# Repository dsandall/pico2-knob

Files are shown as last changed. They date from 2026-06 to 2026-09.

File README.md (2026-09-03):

# pico2-knob

A small **wireless BLE control puck**: a knob (rotary encoder), an OLED screen, and three
buttons, on a round Ø80 mm 2-layer PCB, powered by a **nice!nano v2** (nRF52840) + LiPo.

> Name is legacy — it started as an RP2350/Pico 2 board, then moved to the nice!nano for
> wireless. This repo is the hardware (schematic + layout), a rough mechanical mockup, and
> `firmware/` — currently just bring-up firmware (Rust/Embassy, UF2) for the soldered board:
> LED heartbeat plus encoder/button events over USB serial. No screen, battery or BLE yet.

## Open it
`hardware/pico2-knob.kicad_pro` in **KiCad 10**. The schematic embeds its symbols and the
board embeds its footprints, so it opens standalone; `lib/marbastlib` (nice!nano sym/fp) and
the project lib-tables are included so libraries resolve cleanly too.

## Board summary
- **MCU:** nice!nano v2 — mounted on the **back**, on female sockets, USB-C facing the top
  rim (charge/flash; the device is otherwise sealed and battery-powered over BLE).
- **Encoder:** Alps EC11 w/ pushbutton, shaft at the puck center.
- **Buttons:** 3 × 6 mm tactile (SW_PUSH_6mm), in an arc below the knob.
- **Display:** ER-OLED1.12-2 (SH1107) on a 20-pin ribbon connector (J3, ER-CON20HT-1),
  driven as 4-wire SPI. Panel VPP comes from a 12 V boost (U2, MC34063) off +BATT,
  gated by Q1 from `12V_EN`.
- **Power:** LiPo on a JST-PH (J2) → nice!nano on-board charger (BAT+/GND). No power switch
  (nRF52 sleeps at µA; add an inline slide switch in VBAT if you want true-off).
- **Outline:** Ø80 mm round (bumped up from Ø74 for fab edge-clearance on the nano pads).
- 2-layer, GND pours both sides, 55 tracks, 0 vias. **DRC: 0 errors.**

## Net / GPIO map (nRF52 pads)
| Signal | nice!nano pad |
|---|---|
| Encoder A / B / SW | P0.09 / P0.10 / P1.11 (pads 24 / 23 / 22) |
| Buttons 1 / 2 / 3 | P0.31 / P0.02 / P1.15 (pads 17 / 19 / 20) |
| OLED DC / SCLK / SDI | P0.06 / P0.08 / P0.17 (pads 1 / 2 / 5) |
| OLED RES / CS | P0.22 / P0.24 (pads 7 / 8), 10 kΩ pull-ups (R2/R6) |
| 12V_EN (panel rail) | P1.06 (pad 12), active low — R8 pulls Q1's gate to +BATT |
| Power | 3V3 (pad 16), GND, BAT+ → +BATT |

## For the reviewer 👀
This layout was **script-generated** (see `scripts/`) and auto-routed (freerouting), then
hand-touched at the encoder. Please sanity-check freely — a few notes:
- **2 DRC items are intentionally downgraded to warnings:** `pth_inside_courtyard` between
  the back-side socketed nano and the front-side encoder courtyard. The nano sits ~8.5 mm
  below the board on sockets, so there's no real clash — but please confirm you agree.
- The encoder signal nets stack collinearly under the nano; they're hand-routed
  (`scripts/manual_route.py`) and S2's GND return is a manual trace into the south pour
  (`scripts/fix_s2.py`).
- **Not yet done:** mounting features (holes/standoffs) — coming after the enclosure.
- Pin assignment is flexible (nRF52 GPIOs are interchangeable) — happy to remap for cleaner
  routing if you see a better arrangement.

## Layout of this repo
- `hardware/` — KiCad 10 project (schematic, PCB, lib-tables)
- `lib/marbastlib/` — nice!nano symbol + footprint (trimmed to what's used)
- `scripts/` — generators: `gen_sch.py`, `gen_pcb.py`, routing helpers; `*.sh` render/ERC/DRC
- `cad/` — FreeCAD mechanical mockup (`mockup.py`) + component STEP models (`step/`)
- `build/pico2-knob.pdf` — quick-look: schematic + routed layout

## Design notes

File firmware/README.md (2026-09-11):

# pico2joy bring-up firmware

Bring-up firmware for the assembled puck: **no battery, no BLE**. It exists to
answer "did I solder it right?" — it blinks the nice!nano's LED, drives the
SH1107 ribbon OLED, and streams every encoder detent and button edge over USB
serial while mirroring the same state on the screen.

Rust + [Embassy] on the nice!nano v2 (nRF52840), flashed as a UF2 over the stock
bootloader — no debugger or SWD pads needed.

[Embassy]: https://embassy.dev

## Build and flash

```sh
cargo run --release              # build -> UF2 -> reboot the board -> flash it
MONITOR=1 cargo run --release    # ...and attach picocom when it comes back
```

`cargo run` goes through `flash.sh` (wired up as the cargo `runner`). It packages
the ELF as a UF2, asks the running firmware to reboot into UF2 mode — via its `b`
command, falling back to the 1200-baud touch — waits for the drive, copies, and
waits for the app's serial port to reappear. `udisksctl` is used to mount the
drive if your desktop doesn't automount it.

A board that has never been flashed can't reboot itself, so the first time
(or any time you see "board is in the bootloader's serial-only mode"):

1. Plug in USB-C.
2. **Double-tap** the reset button on the nice!nano. A drive named `NICENANO` (or
   `FTHR840BOOT`) appears — a single tap only gets you the bootloader's serial
   port, no drive.
3. `cargo run --release`, or drag `out/pico2joy-bringup.uf2` onto the drive.

The script waits 20 s for the drive, so you can start it and then double-tap;
`WAIT=40` if you want longer. Build without flashing:

```sh
./build.sh                       # -> out/pico2joy-bringup.uf2 (BLE, the default)
./build.sh --no-ble              # -> out/pico2joy-bringup-noble.uf2
./build.sh --offset-1000         # the alternate flash layout, see below
```

The first boot after flashing writes `UICR.NFCPINS` (to free P0.09/P0.10 from the
NFC block, where encoder A/B live) and resets itself once. If that reset lands in
the bootloader's double-tap window, the board comes up in the bootloader instead —
just tap reset once and it runs. This happens at most once per chip.

## Use

Open the app's serial port — a *second* `/dev/ttyACM*` distinct from the
bootloader's, `1209:0001 softek pico2joy bring-up`:

```sh
picocom -b 115200 /dev/ttyACM1     # baud is ignored, it's USB CDC
```

Opening the port prints a banner; then events stream as you use the puck.
Set the port raw first, as picocom and `pico2joy.py` do: Linux hands every
freshly enumerated ttyACM over cooked, with echo on, and a tty with echo on
sends everything the puck prints straight back into its command parser — the
banner alone spells `p`, `i`, `2` and then `b`, a reboot into the bootloader.
The firmware defends itself (`ECHO_PROBE` in `main.rs`): it writes nothing
until DTR is up and the opener has had 100 ms to go raw, and if its own
greeting comes back it ignores single keys until the port is reopened, `#`
lines excepted. So a bare `cat /dev/ttyACM0` gets a warning line rather than a
puck stuck on the `FLASHING` screen.

```
[   12.345] BTN1 down
[   12.501] BTN1 up
[   13.002] ENC cw  detents=1
[   13.410] ENC_SW down
```

Single-key commands:

| key | does |
|---|---|
| `?` | help |
| `p` | inputs, detents, 12V_EN, battery, link state |
| `m` | open/close the on-screen menu (handy without hands on the puck) |
| `d` | next view: cube / gantry / xcarve / now playing / quota / orientation pattern |
| `i` | re-init the display (reset + full init sequence) |
| `f` | flip the panel 180 degrees (COM/segment remap) |
| `+`/`-` | contrast, in steps of 0x10 from the vendor default 0x4F |
| `e` | toggle the 12 V panel rail — panel off first on the way down |
| `w` | toggle the radio (advertising, or starting the BLE link) |
| `v` | verbose: log every encoder quadrature transition, not just detents  |
| `r` | quota screen: ask the bridge to check the vendors now |
| `l` | LED: dark / dim heartbeat / on |
| `b` | reboot into the UF2 bootloader |
| `#…`  | the machine channel — a line for the gantry bridge, not a keystroke |

## The control model

The device is a 3-axis jog controller, so that is the primitive everything else
is a view of: three jog counters plus a selected axis (`AXIS_COUNTS`, `AXIS` in
`main.rs`). **BTN1/2/3 select the axis, the knob jogs the selected one.**

Button-to-axis mapping lives in one line, `BUTTON_AXIS`, currently `Z, X, Y` in
button order; a build that wants `X, Y, Z` changes only that. The console can
drive the same model without hands on the puck: `1`/`2`/`3` select, `,`/`.` jog.

The **cube view** (second in the `d` cycle) renders those counters as a rotating
wireframe cube, with the three counts along the bottom. Hidden-line removal on a
convex solid is just backface culling: an edge is drawn exactly when at least one
of the two faces meeting at it faces the camera, so silhouette edges appear once
and the three edges meeting at the far corner never appear at all. It uses f32
and `libm` rather than fixed point, because the Cortex-M4F has a single-precision
FPU.

The cube's buttons are **momentary**, unlike everywhere else: hold BTN1/2/3 and
the knob jogs that axis and spins the cube about it, and with nothing held the
knob zooms. The knob applies **torque, not position** — a detent adds angular
momentum (about 0.52 rad/s), light drag bleeds it off with a ~5 s half-life, so a
flick sets it coasting and a counter-flick stops it.

The **gantry** and **xcarve** views, right after it, are real machines rather
than a model of one — see below.

## On the puck itself

- **Hold the knob in and turn it to change app.** One gesture reaches all seven
  screens from any of them, in either direction — which is more than `d` can do,
  and it costs no button, because a press was the only thing the knob did.
  The press is decided on release: turn in between and it was a switch, let go
  without turning and it was the menu.
- **Press the knob** to open the menu, **turn** to move, **BTN1/2/3** to select,
  **press the knob again** to leave — it's the same gesture in and out. Rows: `ble`, `12V rail`, `led`, `screen`, `jog step`,
  `home all`, `battery`, `exit` — each showing its current value on the right.
- The title bar says **which screen you are on**, the radio state, and the cell.
  It used to say `pico2joy` and carry a `12V` flag; neither earned its pixels —
  you can see it's the puck, and the rail flag was permanently lit (Q1 is flipped
  on this revision, so the rail can't be gated — and a board whose VPP *is* down
  has a dark panel nobody is reading a flag on). The rail keeps its menu row and
  its line in `p`, which is where a diagnostic belongs.
- Five screens, and every one of them is *about* something. The live input view
  and the all-pixels-on screen used to bracket them; both were bring-up
  instruments rather than things to look at. The pips told you a switch was
  wired, which `p` still reports and every other screen now proves by working,
  and lighting every pixel loaded VPP hard enough to find a weak boost — on a
  board whose rail can't be gated anyway. The orientation pattern stays, because
  a panel mounted the wrong way round is still worth one keystroke.
- **BTN1/2/3 mean whatever the screen is about**: the axis on the gantry, the
  transport on now-playing, the subscription on the quota screen. The knob is
  the same - jog, volume, or which account the gauge is showing.

## Driving a real printer

`tools/pico2joy.py` is the one host-side program: it finds the puck on USB or
BLE and speaks the same line protocol either way.

It serves several apps over that one link. `relay` owns the link and follows
the puck's screen - jog the gantry, turn the knob to the now-playing view and
the same knob is volume - because the machine channel is multiplexed by message
type and the puck announces its view with `#view`. `gantry`, `spotify` and
`quota` are that same relay pinned to one app, for a host that only has the one
job (the printer has no browser; a workstation may have no printer).

```
tools/pico2joy.py scan            # what can see the puck right now
tools/pico2joy.py monitor         # console passthrough
tools/pico2joy.py relay           # every app, following the puck's view
tools/pico2joy.py gantry          # just the gantry (relay pinned to one app)
tools/pico2joy.py xcarve          # just the X-Carve, through CNCJS
tools/pico2joy.py quota           # just the Claude/Codex rate-limit windows
tools/pico2joy.py flash out/pico2joy-bringup.uf2   # reflash, no reset button
tools/pico2joy.py reset uf2|serial|ota             # into a bootloader mode
```

Standard library only for everything over USB — the printer's system Python has
no pyserial, and a bring-up tool that needs a venv is a tool that doesn't get
run. BLE needs `bleak`, declared inline, so `uv run tools/pico2joy.py …` fetches
it and nothing else has to be installed.

Nobody here is a server. The program is a *client* of everything: it opens the
puck's port (or connects to it as a BLE central) and makes HTTP requests to
Moonraker, which is the only real server in the picture. So it runs wherever the
puck is attached — the printer host, or a workstation — with no listening
socket and no discovery. The one hard rule is that a serial port and a BLE
connection each have exactly one owner, so one copy of it owns the puck at a
time.

Run it on the printer, where Moonraker is localhost and trusted:

```
scp tools/pico2joy.py sovol@spi-xi:~/pico2joy/     # plug the puck in there
ssh sovol@spi-xi 'python3 ~/pico2joy/pico2joy.py gantry'   # localhost Moonraker
```

Moonraker only trusts requests from its `trusted_clients`, which is why the
gantry bridge is happiest on the printer. To run it from a workstation instead, pass
`--api-key`, add that host to `trusted_clients`, or let the tool tunnel the port
so the request arrives from localhost:

```
ssh -N -L 17125:127.0.0.1:7125 sovol@spi-xi        # by hand, or:
tools/pico2joy.py gantry --tunnel sovol@spi-xi     # does the forwarding for you
```

The puck is a **view of the machine, never a second copy of it**. Positions and
limits come from the printer; a detent produces a jog *request*, and the number
on screen doesn't move until Klipper reports that the head did. A jog that gets
refused — unhomed axis, mid-print, outside the travel — simply doesn't happen,
instead of leaving the puck lying about where the nozzle is.

Both directions share the console port. `#` opens a line on the machine channel;
every other byte is still a single-key command. Values are integer micrometres,
so neither end rounds twice:

| direction | line | meaning |
|---|---|---|
| host → puck | `#s <x> <y> <z> <homed-bits> <state>` | toolhead state, ~8 Hz |
| host → puck | `#l <xmin> <xmax> <ymin> <ymax> <zmin> <zmax>` | travel limits |
| host → puck | `#?` | identify |
| puck → host | `#j <axis> <delta-um>` | jog request |
| puck → host | `#c home` / `#c home_z` / `#c stop` | named command |
| puck → host | `#v 1` | identify reply |

No `#s` for 1.2 s and the screen says `offline` rather than showing a stale pose.
Jogs are coalesced one frame at a time, so spinning the knob fast becomes one
move rather than a queue of them, and they go out as a saved-state relative move:

```
SAVE_GCODE_STATE NAME=pico2joy_jog
G91
G1 X0.100 F6000
RESTORE_GCODE_STATE NAME=pico2joy_jog
```

On the gantry screen **BTN1/2/3 are X/Y/Z** (not the cube's `BUTTON_AXIS` order),
the knob jogs the selected axis by the step size from the menu (0.01 / 0.1 / 1 /
10 mm), and `home all` in the menu sends `#c home`. Each axis shows its position,
its travel as a bar with the head's place in it, and dashes if it isn't homed.

## Driving the X-Carve

The X-Carve has its own screen, `xcarve`, right after `gantry` — and it is the
same screen: the travel volume with the head in it, BTN1/2/3 for X/Y/Z, the knob
to jog, `home all` to home. Underneath it is a second `gantry::Machine` on its
own message types, the printer's lines with an `x` after the `#` — `#xs`/`#xl`
down, `#xj`/`#xc` up — so the two machines never read each other's state and
one relay could serve both.

The bridge lives on `rpi-xcarve`, the Pi that runs CNCJS next to the machine,
with the puck on its USB:

```
scp tools/pico2joy.py rpi-xcarve.netbird.cloud:pico2joy/
ssh rpi-xcarve.netbird.cloud 'python3 ~/pico2joy/pico2joy.py --link usb xcarve'
```

`tools/pico2joy-xcarve.service` runs the same thing at boot.

**CNCJS stays in charge of the machine.** It owns the X-Controller's serial port,
and the bridge joins that connection the way a second browser tab does, so the
CNCJS page and the puck work side by side. It doesn't take the port from anyone:
close it in CNCJS and the bridge waits until somebody opens it again. It speaks
socket.io over plain HTTP long-polling rather than a websocket, which keeps it
standard library only — the Pi has no pip to reach — and it signs its own token
with the secret in CNCJS's `~/.cncrc`, which is why it runs as the user CNCJS
runs as.

What GRBL changes, next to Klipper:

- **Positions are work coordinates** — the numbers CNCJS shows, the ones you
  zero. The travel limits go down in the same frame (machine travel
  `-$130..0`, shifted by the work offset), so the head still lands in the right
  place in the frame, and re-zeroing moves the limits along with it.
- **"Homed" means "not in Alarm".** GRBL has no per-axis flag; with homing on
  (`$22=1`) it boots into Alarm and stays there until `$H`. The catch is `$X`,
  which unlocks without homing and leaves the limits describing nothing — and
  soft limits are off on this machine (`$20=0`), so nothing below the puck would
  stop an over-travel either. Home it.
- **Jogs are `$J=` moves** — `$J=G91 G21 X0.100 F3000`, Z at 400 mm/min — which
  GRBL 1.1 keeps out of the modal state, so there is nothing to save and restore
  around them. They only go out from Idle, and never while a CNCJS job is running
  or paused: a paused job expects to find the head where it left it.
- `home all` is `$H`. `#xc stop` is a feed hold rather than a reset, so GRBL
  doesn't forget where the head is.
- **The finest jog step is one the machine can always take.** This X-Carve
  moves 0.0375 mm a step in X and Y (`$100`/`$101` = 26.66 steps/mm), so a
  0.01 mm detent mostly moved nothing at all. The bridge works out the coarsest
  axis's step from `$100`–`$102`, rounds it up to the 0.01 mm the screen shows,
  and sends it as `#xr 40`; the puck raises its finest step to 0.04 mm. GRBL
  rounds a move's end to whole steps, so a move at least one step long always
  turns into at least one.

### Zeroing the workpiece

On the `xcarve` screen the menu's first row is **`zero X`**, for whichever axis
BTN1/2/3 last picked; the rest of the menu scrolls below it. It makes the head's
position the work zero on that axis — `G10 L20 P1 X0` on the active coordinate
system, what CNCJS's zero buttons send. It takes a second press within three
seconds (the row says `again?`), because a stray zero throws away a workpiece
you already touched off. Once it zeroes, the menu closes and the axis reads 0.00.

So, per axis: jog to the spot, press that axis's button, click the knob, and
press a button twice on `zero`.

## Now playing (Spotify, or anything)

`tools/pico2joy.py spotify` turns the puck into a transport for whatever the
host is playing, and relays the album art back to the screen.

```
tools/pico2joy.py spotify              # over USB or BLE, whichever the puck is on
uv run tools/pico2joy.py spotify       # album art needs pillow, fetched by uv
```

It reads the **active MPRIS player** through `playerctl` (following `playerctld`,
so it tracks whatever you last touched) rather than Spotify's Web API - no OAuth,
no app registration, nothing to break when the API changes, and it works against
the Spotify *web player* in your browser exactly as it works against a desktop
app or, for that matter, a YouTube tab. Volume is the host's own output level via
`wpctl` (or `pactl`), because "louder" means the machine the music comes out of.

On the **now-playing screen** (fourth in the `d` cycle) the cover fills the frame
with a dark footer carrying title, artist and a volume bar. **BTN1/2/3 are
previous / play-pause / next**, and the **knob is volume**, five percent a detent.
With no bridge running the screen says so instead of showing a stale track.

The wire format is the same machine channel the gantry uses (`src/media.rs`):
`#ns`/`#nt`/`#na` carry play state, title and artist; the 128x128 one-bit cover
goes out as `#ab`, a run of `#a <seq> <hex>` rows, then `#ae`; and the puck sends
`#m p`/`#m n`/`#m b`/`#m v <steps>` back. One owner per link still holds, so the
puck drives the gantry or the player, not both at once.

## Subscription quotas

`tools/pico2joy.py quota` puts the state of your Claude and Codex plans on the
puck: how much of each short window is spent, how much of the week, how long
until the short one starts again, and how many sessions are running.

```
tools/pico2joy.py quota                       # ~/.claude and ~/.codex
tools/pico2joy.py quota --claude ~/.claude=me \
                        --claude work-box:~/.claude=work \
                        --codex ~/.codex
```

It reads the credentials each vendor's own CLI already keeps on disk and asks
the same usage endpoints those CLIs ask — `/api/oauth/usage` for Claude, the
ChatGPT backend's `wham/usage` for Codex. Nothing is counted here and nothing is
reconstructed from transcripts: a local token tally would be a second, wronger
copy of a number the vendor is authoritative for, which is the same reason the
gantry screen waits for Klipper rather than integrating its own jogs.

**Read-only, deliberately.** The access tokens in those directories are the
CLIs' to refresh; using the refresh token here could rotate it out from under a
running session and log you out of your own editor to draw a bar on a knob. So
an expired token shows `log in again` and waits for its CLI to renew it, which
happens the next time you use it.

The usage endpoints rate-limit, and a 429 is easy to earn and slow to clear — so
the default is a poll every five minutes, a 429 holds the last good reading
rather than blanking the screen, and the interval doubles on each failure until
it succeeds. Anthropic's `Retry-After` is honoured where it says anything useful
(it currently sends `0`). Five minutes of staleness costs nothing when holding a
button re-checks on demand, and `--refresh` moves it.

### More than one plan, and plans on other machines

The default is whatever is logged in on this machine, which for one Claude
subscription and one Codex is the whole configuration. **A second Claude account
needs a second config directory**, because Claude Code keeps one login per
directory and `/login` replaces it:

```sh
CLAUDE_CONFIG_DIR=~/.claude-work claude       # log the other account in, once
tools/pico2joy.py quota --claude ~/.claude=me --claude ~/.claude-work=work
```

If the other account lives on **another machine**, give it as `HOST:DIR` — scp's
spelling, and unambiguous because a local config directory has no colon:

```sh
tools/pico2joy.py quota --claude ~/.claude=me \
                        --claude design-desktop:~/.claude=work
```

That ships *this file* to the far end over ssh (`ssh host python3 - probe claude
~/.claude`), which reads the credentials, makes its own request, and prints one
JSON line back. Nothing is installed there and nothing is left behind — the same
bargain the rest of this tool makes. The token never crosses the network either:
`cat`ing the credentials home and calling the API from here would work, but there
is no reason to move a live OAuth token when the machine holding it can send back
six numbers instead. `tools/pico2joy.py probe claude ~/.claude` runs the same
reading locally, which is a good way to see exactly what the bridge sees.

`--claude`/`--codex` take `[HOST:]DIR` or `[HOST:]DIR=LABEL`; the label is what
shows on the row, and thirteen characters of it fit. Without one it takes the
account's display name or the local part of its email. Three accounts is the
limit — three buttons, three rows.

### On the screen

One block per account, all of them drawn all of the time. A name line carrying
the vendor, the sessions badge and the countdown to the short window's reset,
then a fat bar for that window and a thinner one for the week:

```
quota                     ble  88%
claude Dylan          [9]  1h47m
 5h ██████████████░░░░░░░░░  64%
 7d ███████░░░░░░░░░░░░░░░░  29%
codex engineering          1h12m
 5h ███████████████████████ 100%
 7d ██░░░░░░░░░░░░░░░░░░░░░   5%
```

Each bar carries its own label and number, drawn twice and clipped either side
of the fill boundary — lit over the empty part, dark over the filled part — so
the text stays legible at every value instead of vanishing into the bar around
half way. That is what buys the room for six bars on a 128-pixel screen without
a caption line above each one.

There is **nothing to select and nothing to page through**, which is the point:
the question this screen answers is "where do I stand", and an answer you have to
press a button to finish reading is a worse answer. **Holding a button** asks the
bridge to look again — the answer to "has it reset yet?" — and that is the only
control here. From the console that is `r`.

**Window names come from the bridge**, not from a constant in the firmware: `5h`
today, `6h` if a vendor moves, and **`7d/Fable`** when the weekly cap that
actually binds is one scoped to a model. Claude reports both an all-models weekly
figure and per-model ones, and the scoped one runs out first — a week that is 29%
gone overall can be 41% gone on the model you are using. The bar shows whichever
is higher and its label says which, because the useful number is the one you will
hit, not the flattering one.

**The badge is running sessions.** Neither vendor reports this, so it is counted
where the answer exists: the machine that account is logged in on, over the same
ssh hop as the reading. Top-level processes only — a session spawns helpers with
the same name, so counting every `claude` in `ps` says nine when three windows
are open — attributed by each process's `CLAUDE_CONFIG_DIR` (or `CODEX_HOME`), so
two accounts on one machine are counted apart. It is drawn only when there are
any, so an idle plan's line stays clean and a busy one announces itself.

The countdown is the one number computed on the puck. The bridge sends the
seconds left at the moment it asked and the puck turns that into a deadline on
its own clock, so the minutes tick between polls instead of freezing; every poll
re-syncs it. The host stays the authority and the puck only interpolates — the
same bargain the gantry makes with the toolhead position.

The wire format is the same machine channel (`src/quota.rs`): `#qz <count>` is
the heartbeat, `#qa` names a slot and its two windows, `#qu` carries the two
windows as percent and seconds-to-reset plus the session count and state, and the
puck sends `#q r` back. The vendors are polled on a worker thread, because a
usage request is a round trip to the internet and the loop that does it is also
the loop that reads the knob.

## Staying connected over BLE

The relay is happiest on the cable, but it does not need one. `--link ble` puts
it on the radio and keeps it there:

```
uv run tools/pico2joy.py --link ble relay --claude ~/.claude=me --codex ~/.codex
```

**This is the default build**, so `./build.sh`, `cargo run` and
`tools/pico2joy.py flash` all put it on the puck. `./build.sh --no-ble` gives the
broadcast-only firmware instead: a quarter of the flash, no radio stack to go
wrong, and no way to accept a connection — a useful thing to fall back to when
you are bisecting something, and useless for anything in this section.

**The link puts itself back together.** `BleLink`'s thread is not there to
connect once; it scans, connects, serves until the link drops, and starts again,
for as long as the program runs. Nothing above it knows. A forced disconnect
costs about four seconds:

```
14:37:32 ble: link down
14:37:36 ble: connected to C5:96:2F:91:CE:B8
14:37:37 relay: link back, resending
```

That last line is the part that matters. A puck that reconnected is a puck that
was told the toolhead position, the album art and three subscriptions before the
gap and remembers none of it, so the link counts its connections and the relay
resends everything on every new one — not just the first. Lines queued while the
link is down are **dropped**, not buffered: a jog delivered thirty seconds late
is worse than a jog that never happened.

`--link auto` still prefers the cable, and falls back to the radio when the cable
goes away — so unplugging USB mid-session moves the relay onto BLE rather than
ending it.

### Making Linux hold the link

Two things on the host are worth checking, because neither is our code:

**USB autosuspend on the Bluetooth controller.** This is the big one. `btusb`
ships with `enable_autosuspend=Y`, and on the MediaTek combo cards (`0e8d:*`, the
MT7921/7922 family) a suspended controller drops LE links and is slow to come
back. Check what yours has done:

```sh
cat /sys/class/bluetooth/hci0/device/../power/control          # "auto" is the problem
cat /sys/class/bluetooth/hci0/device/../power/runtime_suspended_time   # in ms
```

Pin it on, for this boot and for every boot:

```sh
echo on | sudo tee /sys/class/bluetooth/hci0/device/../power/control

# /etc/udev/rules.d/81-bt-no-autosuspend.rules — use your own vendor:product
ACTION=="add", SUBSYSTEM=="usb", ATTR{idVendor}=="0e8d", ATTR{power/control}="on"
```

**BlueZ's supervision timeout.** The central picks the connection parameters and
the puck has no say in them (see `src/ble.rs` for why — the GAP preferred-
parameters characteristic is a TODO in trouble-host 0.8). BlueZ's default tears
the link down over one missed window, which is easy to earn from a device you
pick up and carry. Four seconds of tolerance in `/etc/bluetooth/main.conf`:

```ini
[LE]
MinConnectionInterval=24
MaxConnectionInterval=48
ConnectionLatency=0
ConnectionSupervisionTimeout=400
```

(Units are 1.25 ms for the intervals and 10 ms for the timeout, so that is
30–60 ms and 4 s.) Then `systemctl restart bluetooth`. This is an optimisation
rather than a fix — the link recovers either way — but it turns a four-second
gap into no gap.

One more, if a connection succeeds and then behaves as though the puck has no
services: BlueZ caches a GATT database per address, and the puck's bootloader
advertises from an address one digit from the application's. The bridge notices
an empty service list and drops the cached record itself before retrying, so
this should heal on its own; `bluetoothctl remove <address>` is the manual
version, and `bluez-utils` is worth having installed for exactly that kind of
poking.

## Battery

The nice!nano v2 senses the cell through **VDDH**, not a divider pin, so this
samples VDDH/5 on the SAADC against the internal 0.6 V reference at gain 1/6:

    millivolts = raw * 18000 / 4096

Percent comes from a piecewise LiPo curve (`state::percent_from_mv`), because a
straight voltage-to-percent line is useless on a cell that sits at 3.8 V for
most of its life.

Two things to expect. On USB with no cell it reads about **4.54 V** — VBUS less
the input diode drop — and therefore claims 100%. And while charging it reads
the charger's output rather than the cell, so it will read full before the cell
is. Neither is worth correcting until a battery is actually on J2.

## What this actually tests

- nice!nano seated in its sockets, USB and the on-module LED alive.
- All three buttons, the encoder push, and both encoder phases. A cold joint on
  one encoder phase shows up as `step=0` noise under `v` instead of clean detents.
- The switch pull-ups at boot: `p` flags anything already reading low (a held
  button, or a short to GND on that net).
- **The SH1107 panel** on the J3 ribbon: the boot splash is an orientation test
  pattern (border, both diagonals, a solid block and `TL` in the top-left), then
  it switches to the cube, which is a live view of the encoder and the buttons
  in its own right: hold a button and turn, and the cube spins.
- **U2, the 12 V boost**, which the panel needs as external VPP (11.5–12.5 V, the
  panel's own DC-DC stays off via `0xAD 0x8A`). Brought up after the controller
  is initialised and dropped before it, and `e` toggles it.

Untested: the LiPo path (J2, `VBAT`).

### If the screen looks wrong

- **Mirrored or upside down** — press `f`. That flips COM scan and segment remap
  (`0xC8 0xA1` vs `0xC0 0xA0`), which is the assembly-orientation case.
- **Rotated 90 degrees** — already handled. This panel's RAM sits 90 degrees to
  the glass (an SH1107 page runs along the horizontal), and the controller only
  offers 180, so `Display::set_pixel` rotates on the way into the framebuffer:
  logical `(x, y)` lands at panel column `y`, row `127 - x`. If a future panel
  wants the plain mapping, that one line is the only thing to change — and note
  a bare transpose (column `y`, row `x`) rotates *and* mirrors.
- **Nothing at all, or faint** — check TP4 for ~12 V (`e`), then try `+` a few
  times. VPP below ~11.5 V reads as a dim or blank panel rather than an error.
- **Garbled but alive** — drop `spim::Frequency::M4` in `main.rs` to `M2`.

## Pinout

| Signal | nRF52840 | pad | Notes |
|---|---|-----|---|
| LED | P0.15 |  -  | on-module blue LED, active high |
| VCC_EN | P0.13 |  -  | nice!nano load switch: high = 3V3 pad live  |
| ENC_A | P0.09 | 24  | NFC pin, freed via `nfc-pins-as-gpio` |
| ENC_B | P0.10 | 23  | likewise |
| ENC_SW | P1.11 | 22  | |
| BTN1 | P0.31 | 17  | |
| BTN2 | P0.02 | 19  | |
| BTN3 | P1.15 | 20  | |
| OLED_DC | P0.06 |  1  | SH1107, 4-wire SPI over the J3 ribbon |
| OLED_SCLK | P0.08 |  2  | |
| OLED_SDI  | P0.17 |  5  | |
| OLED_RES  | P0.22 |  7  | 10k pull-up R2: boots out of reset |
| OLED_CS | P0.24 |  8  | 10k pull-up R6: boots deselected |
| 12V_EN | P1.06 | 12  | Q1 gate, **active low** — see below |

Taken from `board_pico2knob/pico2-knob.kicad_sch` (the checked-in
`bom_netlist.xml` is older than the ribbon-OLED rework — don't use it).

### 12V_EN is active low, and on this revision "off" isn't off

R8 pulls Q1's gate up to +BATT, so the rail is off with the gate high and on with
it pulled down. 3V3 is *not* a clean off — it leaves Vgs near -0.9 V, inside the
DMG3415U's threshold band — so the firmware drives the pin **low to enable** and
leaves it **disconnected (high-Z) to disable**, never high.

That said, Q1 looks flipped, so the rail can't actually be gated on this build:

- the schematic has Q1's **drain** on +BATT and its **source** on U2's Vin;
- the PCB footprint renames the SOT-23 pads `G`/`S`/`D` onto pads 1/2/3, which is
  exactly the DMG3415U's real pinout — so the physical drain is the +BATT one.

A P-channel high-side switch needs its *source* on the supply. Wired this way the
body diode (drain → source) conducts +BATT into U2's Vin whenever a cell or USB is
present, so U2 free-runs and the 12 V rail is always live, burning its quiescent
current on battery. `e` then only removes the diode drop rather than switching
anything.

To confirm on the bench: meter TP4 right after boot, before touching `e`. ~12 V
means the diode path is feeding U2. The rev-2 fix is swapping Q1's source and
drain (or dropping the FET and using U2's own shutdown).

## Flash layout / the two UF2s

The stock bootloader starts the app at **0x26000**, above the (unused) SoftDevice
slot, and asks the MBR to forward interrupts there — the same slot ZMK uses. That
is `out/pico2joy-bringup.uf2`, and it's the one to use. It carries the BLE stack;
`out/pico2joy-bringup-noble.uf2` (`./build.sh --no-ble`) is the same firmware
without it, and links at the same address.

If the bootloader on your board was built without a SoftDevice it will expect the
app at 0x1000 instead, and copying the default UF2 will appear to do nothing (the
drive just remounts). `out/pico2joy-bringup-0x1000.uf2` (`./build.sh
--offset-1000`) is linked for that case. `INFO_UF2.TXT` on the bootloader drive
names the bootloader build if you want to check first.

Neither variant touches the bootloader itself (0xF4000+), so double-tap reset
always gets you back.

## Next

- Battery: read VDDH via SAADC for a rough LiPo percentage (the nice!nano v2
  senses the cell through VDDH, not a divider pin).
- Sleep: the panel and the 12 V rail dominate the power budget, so idle wants
  display-off plus VPP down — which needs the Q1 fix above to actually work.
- BLE HID over `nrf-softdevice` or `trouble`, which is where the app at 0x26000
  starts mattering: a SoftDevice build has to move up to 0x27000.

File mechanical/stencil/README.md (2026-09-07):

# 3D-printed solder paste stencils

Generated with KiKit from `board_pico2knob/pico2-knob.kicad_pcb`.

## Which file to print

| Process | Top side | Bottom side |
|---|---|---|
| **FDM, 0.4 mm nozzle** | `topStencil-fdm.stl` | `bottomStencil-fdm-noJ3.stl` |
| **Resin (MSLA)** | `topStencil.stl` | `bottomStencil-noJ3.stl` |

The `-fdm` files have apertures enlarged 0.05 mm per side to offset FDM hole
shrinkage. Print them on FDM only — on resin they would over-dispense.

J3 is omitted from every bottom stencil meant for printing. `bottomStencil.stl`
retains it for reference only; see [J3](#j3).

## Regenerate

```sh
# resin
kikit stencil createprinted --pcbthickness 1.6 --thickness 0.2 \
  --framewidth 1.5 --frameclearance 0.1 \
  board_pico2knob/pico2-knob.kicad_pcb mechanical/stencil

# FDM (both sides, J3 omitted)
kikit stencil createprinted --pcbthickness 1.6 --thickness 0.2 \
  --framewidth 1.5 --frameclearance 0.1 --enlargeholes 0.05 --ignore J3 \
  board_pico2knob/pico2-knob.kicad_pcb mechanical/stencil/_fdm
```

KiKit always writes `topStencil.*` and `bottomStencil.*` into the output dir, so
the second run needs its files renamed to the `-fdm` names above and their
`.scad` DXF paths repointed at the top-level `.dxf` files. `--enlargeholes` is
applied in OpenSCAD, not in the DXF export, so both runs emit identical DXFs and
only one copy is kept.

Add `--ignore J3` to the first command for `bottomStencil-noJ3.*`.

## Parameters

| Option | Value | Why |
|---|---|---|
| `--pcbthickness` | 1.6 mm | board stackup thickness |
| `--thickness` | 0.2 mm | aperture depth = paste volume. 0.15 is closer to a steel stencil but is fragile printed; 0.3 would over-dispense onto U2's 0.6 mm pads and bridge |
| `--framewidth` | 1.5 mm | registration lip around the outline |
| `--frameclearance` | 0.1 mm | slip fit over the PCB edge; 0 is a press fit that print tolerance won't hit |
| `--enlargeholes` | 0.05 mm | FDM only — recovers hole shrinkage |

## Geometry

All variants 54.15 × 102.72 × 1.5 mm, watertight (0 non-manifold edges).
Height is 0.2 mm of stencil plate plus a 1.3 mm register lip that grips the
board edge.

Measured from the exported meshes, sliced mid-plate at z = 0.1 mm:

| File | Apertures | Min width | Min web | Web @ 0.33 mm extrusion |
|---|---|---|---|---|
| `topStencil.stl` | 19 | 0.600 mm | 0.655 mm | 2.0× |
| `topStencil-fdm.stl` | 19 | 0.700 mm | 0.553 mm | 1.7× |
| `bottomStencil-noJ3.stl` | 8 | 1.149 mm | 1.266 mm | 3.8× |
| `bottomStencil-fdm-noJ3.stl` | 8 | 1.249 mm | 1.166 mm | 3.5× |

The *web* is the wall left standing between adjacent apertures. On FDM it must
hold at least one extrusion, which is what constrains this board — not the
aperture width.

Per-part, from the board:

| Part | Side | Min aperture | Min web | Area ratio @0.2 mm |
|---|---|---|---|---|
| L1 | B | 2.90 mm | 7.00 mm | 4.72 |
| D1 | B | 1.80 mm | 1.50 mm | 2.62 |
| C1–C6 | F/B | 1.15 mm | 1.80 mm | 1.75 |
| U2 SOIC-8 | F | 0.60 mm | 0.67 mm | 1.15 |
| Q1 SOT-23 | F | 0.60 mm | 0.66 mm | 1.07 |
| J3 FPC | B | 0.30 mm | **0.20 mm** | **0.61** |

Area ratio > 0.66 is the paste-release rule, independent of process.

## Slicer settings — FDM

- **Extrusion width 0.33 mm.** This is the one setting that matters. The tightest
  web is 0.553 mm (Q1, U2); at the default 0.42 mm width that is 1.3 extrusions
  and the slicer may merge the two perimeters into a blob or drop the wall
  entirely. At 0.33 mm it is 1.7×, enough for a clean wall.
- **Layer height 0.1 mm**, so the 0.2 mm plate is 2 layers rather than 1. A
  single-layer sheet this size is floppy and delaminates from the frame.
- No supports inside the apertures; print plate-side down, flat on the bed.
- Turn off elephant-foot compensation — it eats the aperture edges, which the
  0.05 mm enlargement has already accounted for.

`bottomStencil-fdm-noJ3.stl` is undemanding (1.166 mm webs) and prints on
defaults. Only the top stencil needs the width change.

## J3

`bottomStencil.stl` includes J3 (ER-CON20HT-1, 0.3 mm apertures on 0.5 mm
pitch). Its 0.20 mm web is under half an extrusion, and its 0.61 area ratio
fails the release rule even for laser-cut steel at this thickness. It is kept
only as a reference for ordering a thinner steel stencil later. Drag-solder or
hot-air J3 by hand.

## Use

1. Paste and reflow the bottom side first, while the top is still bare and sits
   flat.
2. Then the top side. L1 (12×12×6 mm) and U1 on the bottom stand proud, so
   support the board on a jig or foam — the stencil registers only on the
   perimeter and will rock otherwise.
3. Hand-solder J3.
4. THT parts (R1–R8, SW1–SW3, RE1, J2) go in after both reflows.

## Files

`*.scad` is the OpenSCAD source; `*.dxf` are the paste and Edge.Cuts exports it
imports. The `.scad` files reference the `.dxf` files by **absolute path**, so
moving this directory breaks re-rendering — but not the already-exported STLs.
Regenerate rather than relocate.

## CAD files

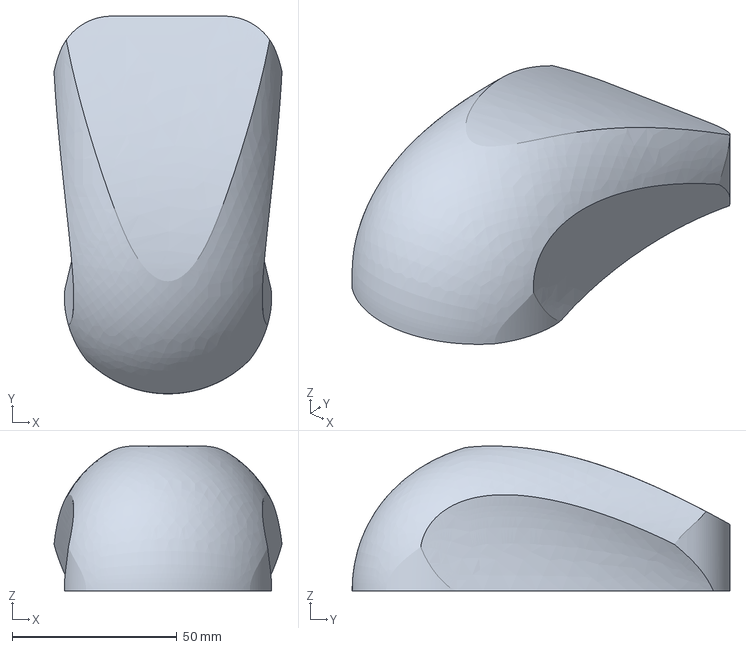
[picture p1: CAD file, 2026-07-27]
mechanical/pico2_housing-AssemblyBody001.3mf
69.2 x 114.7 x 44.0 mm

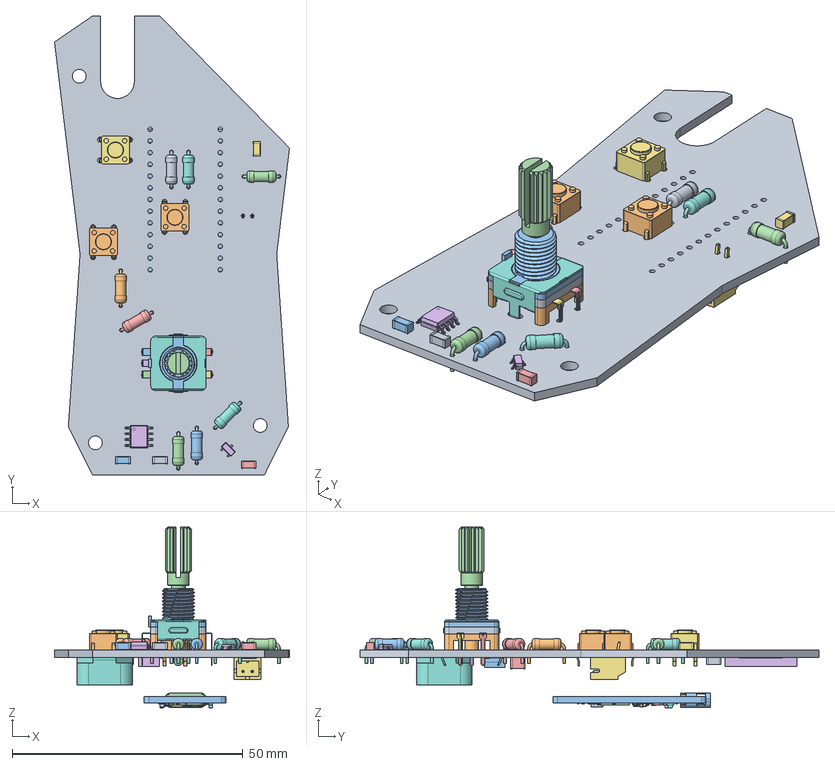
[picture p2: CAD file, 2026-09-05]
board_pico2knob/pico2-knob.FCStd
51.0 x 99.5 x 39.2 mm
Pcb_8413
R3_R_Axial_DIN0207_L63mm_D25mm_P762mm_Horizontal_b51420537963
R7_R_Axial_DIN0207_L63mm_D25mm_P762mm_Horizontal_70fc23c8098c
R5_R_Axial_DIN0207_L63mm_D25mm_P762mm_Horizontal_7fab57a37c6b
R4_R_Axial_DIN0207_L63mm_D25mm_P762mm_Horizontal_c194fff2a282
Q1_SOT-23_32ed8c65a565
SW1_SW_PUSH_6mm_cfd07b67f05b
R2_R_Axial_DIN0207_L63mm_D25mm_P762mm_Horizontal_00e29c8c2e55
R6_R_Axial_DIN0207_L63mm_D25mm_P762mm_Horizontal_02b1f0690d52
SW3_SW_PUSH_6mm_56e492052e4b
C1_C_1206_3216Metric_e4e47fb66cdf
R1_R_Axial_DIN0207_L63mm_D25mm_P762mm_Horizontal_7a0b37df3640
C3_C_1206_3216Metric_2f17a97e88e6
U2_SOIC-8_3.9x4.9mm_P1.27mm_75e6328f15f4
C5_C_1206_3216Metric_ec0d8f619cf6
R8_R_Axial_DIN0207_L63mm_D25mm_P762mm_Horizontal_82f2dfd283f3
C6_C_1206_3216Metric_844f209512eb
SW2_SW_PUSH_6mm_a63fb34835cf
EC11_Rotary_Encoder_Switched
EC11_Rotary_Encoder_Switched001
EC11_Rotary_Encoder_Switched002
EC11_Rotary_Encoder_Switched003
EC11_Rotary_Encoder_Switched004
EC11_Rotary_Encoder_Switched005
EC11_Rotary_Encoder_Switched006
EC11_Rotary_Encoder_Switched007
EC11_Rotary_Encoder_Switched008
EC11_Rotary_Encoder_Switched009
C2_C_1210_3225Metric_91bc0c7a5d6c
J3_Body_830cd876cd33
J2_JST_S2B_PH_K_9cea29381e0c
L1_L_Coilcraft_MSS1260-XXX_a52a64321d5b
C4_C_1206_3216Metric_ee5089a455c9
nice!nano v1.0
nice!nano v1.001
nice!nano v1.002
nice!nano v1.003
nice!nano v1.004
nice!nano v1.005
nice!nano v1.006
nice!nano v1.007
nice!nano v1.008
nice!nano v1.009
nice!nano v1.010
nice!nano v1.011
nice!nano v1.012
nice!nano v1.013
nice!nano v1.014
nice!nano v1.015
nice!nano v1.016
nice!nano v1.017
nice!nano v1.018
nice!nano v1.019
nice!nano v1.020
nice!nano v1.021
nice!nano v1.022
nice!nano v1.023
nice!nano v1.024
nice!nano v1.025
nice!nano v1.026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

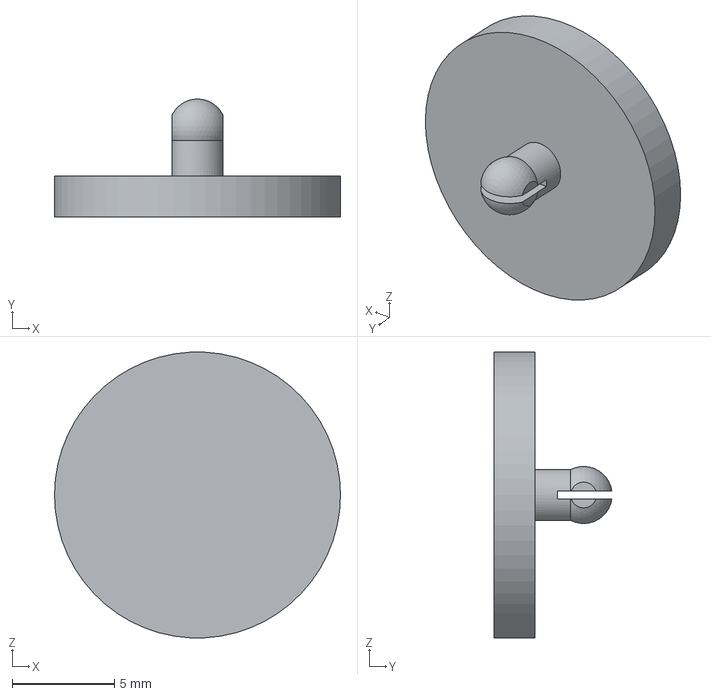
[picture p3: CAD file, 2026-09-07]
mechanical/pcb_nubbin_mount-Body.step
14.0 x 5.77 x 14.0 mm

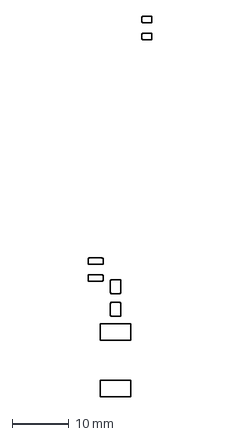
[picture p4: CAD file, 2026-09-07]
mechanical/stencil/pico2-knob-PasteBottom-noJ3.dxf
11.2 x 66.9 mm

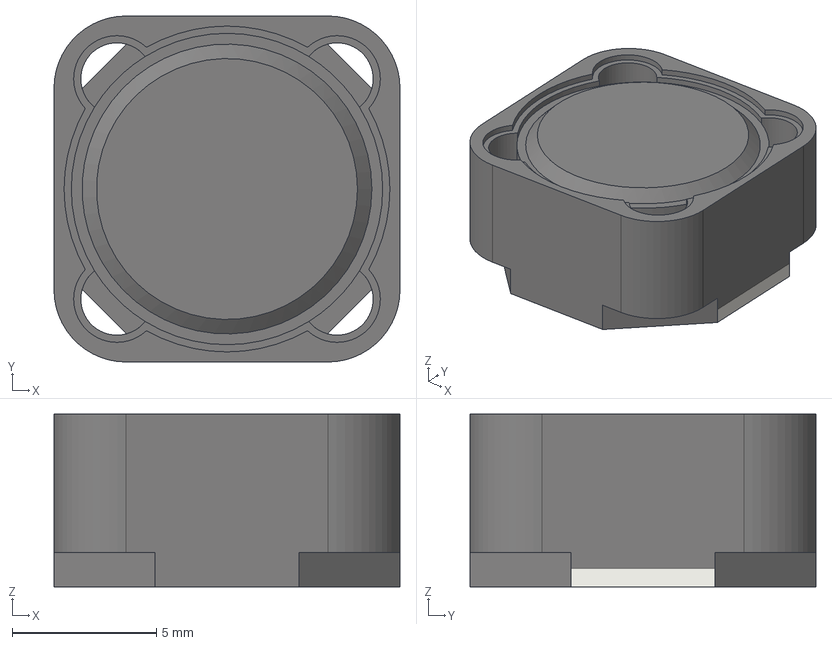
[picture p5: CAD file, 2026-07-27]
mechanical/step/inductor.step
12.0 x 12.0 x 6.00 mm

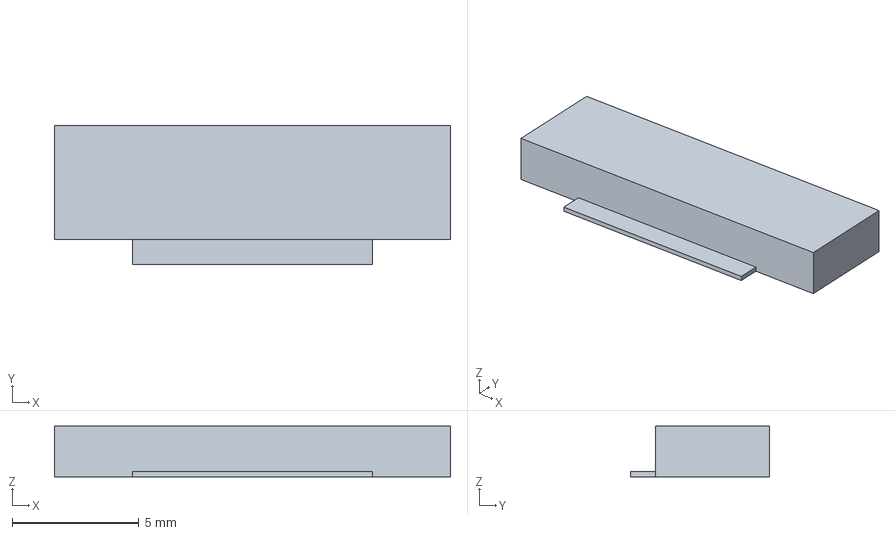
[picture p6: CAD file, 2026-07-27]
board_pico2knob/ribbon_con.FCStd
15.6 x 5.50 x 2.00 mm

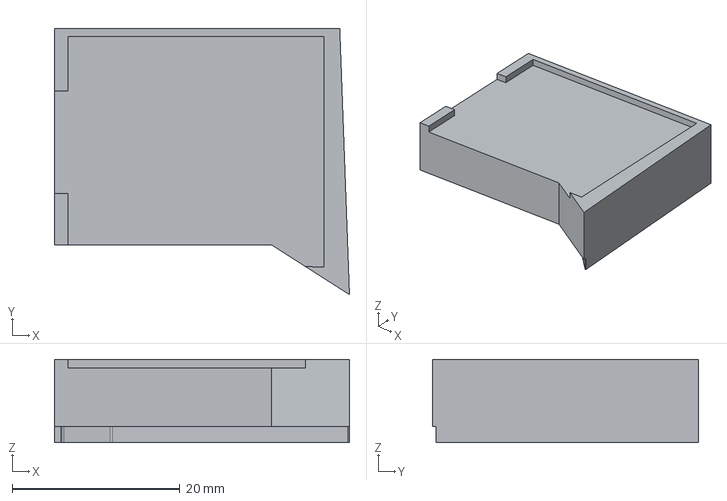
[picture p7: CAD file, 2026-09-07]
mechanical/pico2_housing-v2Pad008.step
35.2 x 31.8 x 9.90 mm

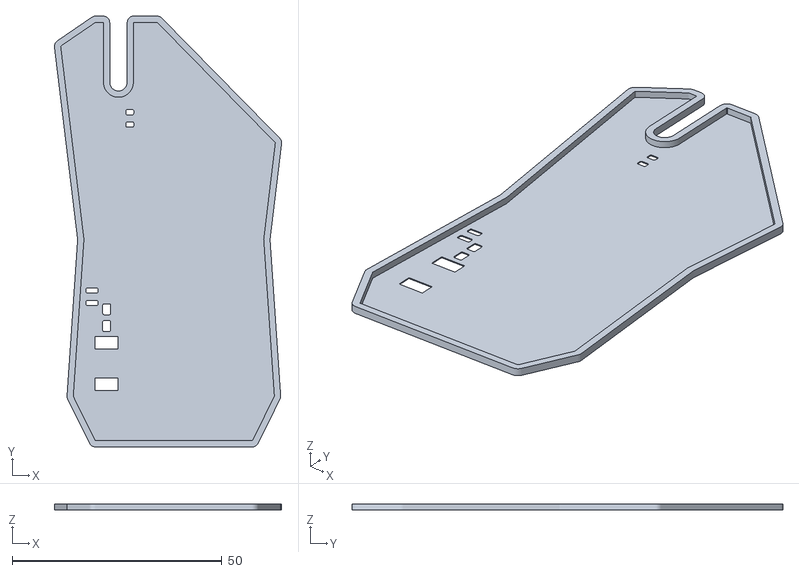
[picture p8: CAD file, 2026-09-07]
mechanical/stencil/bottomStencil-fdm-noJ3.stl
54.1 x 102.7 x 1.50

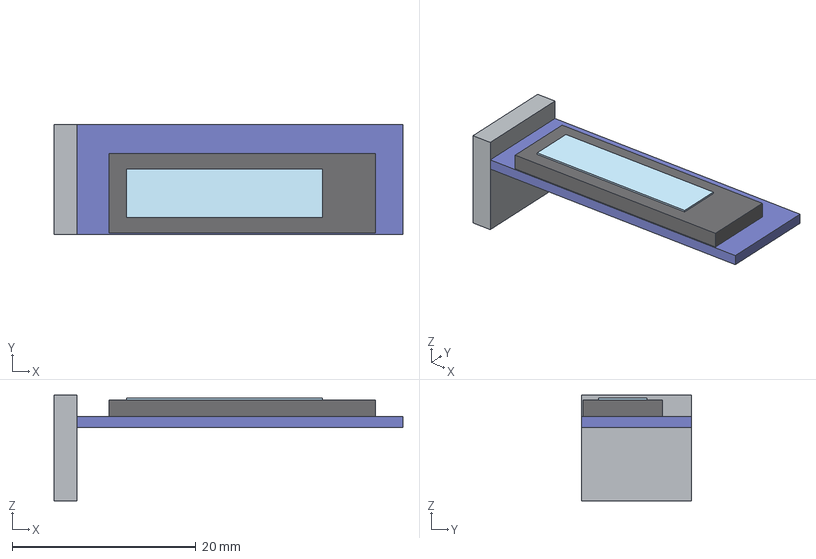
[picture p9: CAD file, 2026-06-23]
mechanical/step/oled.step
38.0 x 12.0 x 11.5 mm
OLED_0_87_0
OLED_0_87_1
OLED_0_87_2

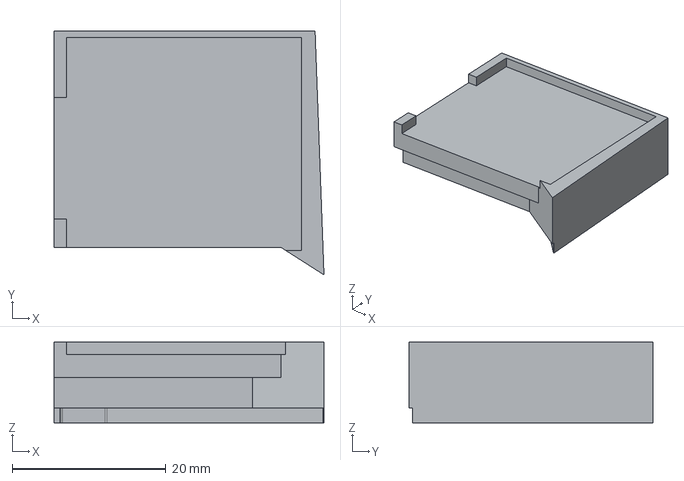
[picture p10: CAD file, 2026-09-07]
mechanical/pico2_housing-v2display back housi.step
35.2 x 31.8 x 10.5 mm

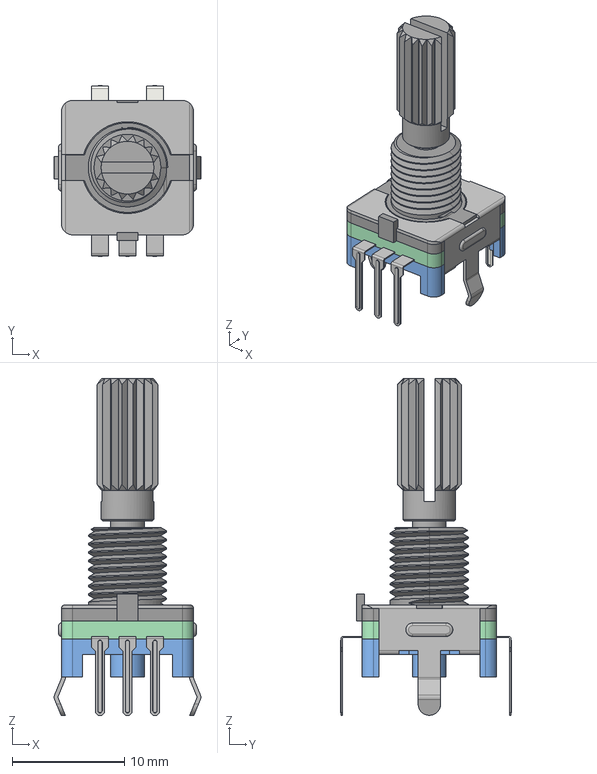
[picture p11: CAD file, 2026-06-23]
mechanical/step/encoder.step
13.1 x 15.3 x 30.1 mm

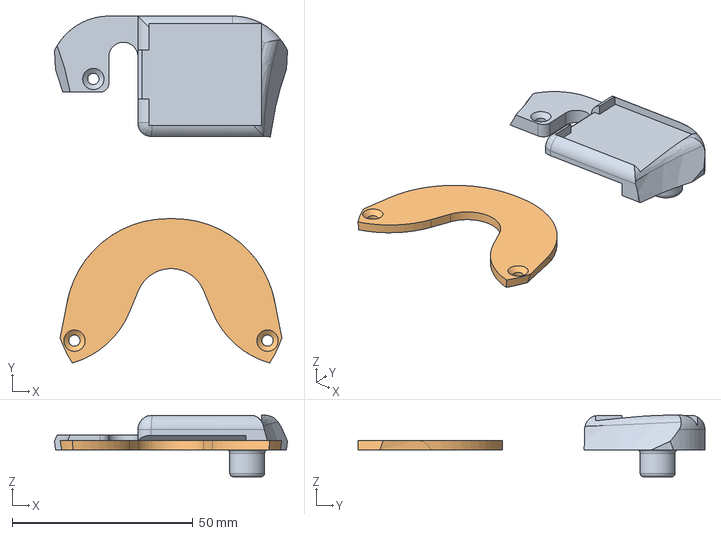
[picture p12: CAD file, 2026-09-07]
mechanical/pico2_housing-v2shell_upper.step
64.5 x 96.1 x 17.1 mm

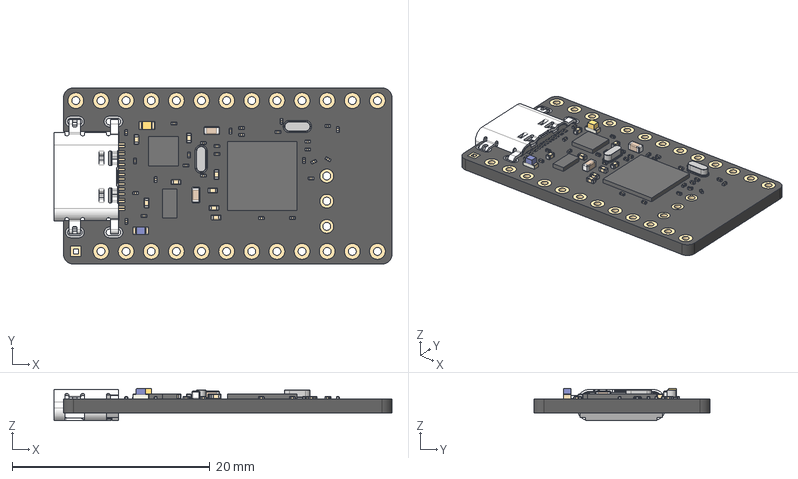
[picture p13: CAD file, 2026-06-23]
mechanical/step/nicenano.step
34.2 x 17.8 x 3.28 mm
nice!nano v1.0
SSOP16
LED_0603_1608Metric_ON
LED_0603_1608Metric_ON_1
Crystal Oscillator
Crystal Oscillator_1
usb4520-03-0-a_1
C0201 x 21
C0402 x 8
C0201_1 x 7

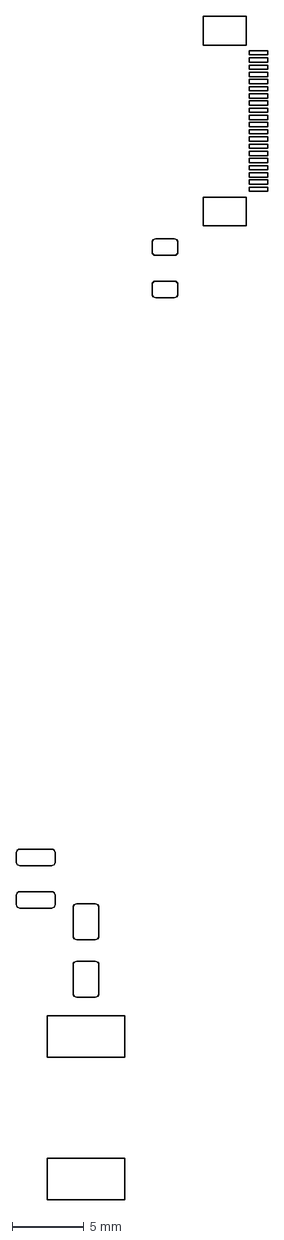
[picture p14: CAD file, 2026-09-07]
mechanical/stencil/pico2-knob-PasteBottom.dxf
17.5 x 82.4 mm

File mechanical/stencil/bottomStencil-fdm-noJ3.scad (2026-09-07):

// Generated by SolidPython 1.1.3 on 2026-08-31 21:13:46
$fa = 0.4; $fs = 0.4;


rotate(a = 0, v = [1, 0, 0]) {
	difference() {
		scale(v = [1, 1, 1]) {
			difference() {
				linear_extrude(height = 1.5000000000) {
					offset(r = 1.6000000000) {
						import(file = "/home/thebu/newhome/softek/pico2-knob/mechanical/stencil/pico2-knob-EdgeCuts.dxf", origin = [0, 0]);
					}
				}
				translate(v = [0, 0, 0.2000000000]) {
					linear_extrude(height = 1.5000000000) {
						offset(r = 0.1000000000) {
							import(file = "/home/thebu/newhome/softek/pico2-knob/mechanical/stencil/pico2-knob-EdgeCuts.dxf", origin = [0, 0]);
						}
					}
				}
			}
		}
		linear_extrude(center = true, height = 0.8000000000) {
			offset(chamfer = false, delta = 0.0500000000) {
				import(file = "/home/thebu/newhome/softek/pico2-knob/mechanical/stencil/pico2-knob-PasteBottom-noJ3.dxf", origin = [0, 0]);
			}
		}
	}
}
/***********************************************
*********      SolidPython code:      **********
************************************************
 
import pcbnew
import numpy as np
import json
from collections import OrderedDict
from kikit.common import *
from kikit.defs import *
from kikit.substrate import Substrate, extractRings, toShapely, linestringToKicad
from kikit.export import gerberImpl, pasteDxfExport
from kikit.export import exportSettingsJlcpcb
import solid
import solid.utils
import subprocess
import shutil
from kikit.common import removeComponents, parseReferences

from shapely.geometry import Point


OUTER_BORDER = fromMm(7.5)
INNER_BORDER = fromMm(5)
MOUNTING_HOLES_COUNT = 3
MOUNTING_HOLE_R = fromMm(1)
HOLE_SPACING = fromMm(20)

def addBottomCounterpart(board, item):
    item = item.Duplicate()
    item.SetLayer(Layer.B_Paste)
    board.Add(item)

def addRoundedCorner(board, center, start, end, thickness):
    corner = pcbnew.PCB_SHAPE()
    corner.SetShape(STROKE_T.S_ARC)
    corner.SetCenter(toKiCADPoint((center[0], center[1])))
    corner.SetStart(toKiCADPoint((start[0], start[1])))

    startVector = start - center
    endVector = end - center
    if startVector[0] * endVector[1] - startVector[1] * endVector[0] > 0:
        corner.SetArcAngleAndEnd(fromDegrees(90), True)
    else:
        corner.SetArcAngleAndEnd(fromDegrees(-90), True)
    corner.SetWidth(thickness)
    corner.SetLayer(Layer.F_Paste)
    board.Add(corner)
    addBottomCounterpart(board, corner)

def addLine(board, start, end, thickness):
    line = pcbnew.PCB_SHAPE()
    line.SetShape(STROKE_T.S_SEGMENT)
    line.SetStart(toKiCADPoint((start[0], start[1])))
    line.SetEnd(toKiCADPoint((end[0], end[1])))
    line.SetWidth(thickness)
    line.SetLayer(Layer.F_Paste)
    board.Add(line)
    addBottomCounterpart(board, line)

def addBite(board, origin, direction, normal, thickness):
    """
    Adds a bite to the stencil, direction points to the bridge, normal points
    inside the stencil
    """
    direction = normalize(direction) * thickness
    normal = normalize(normal) * thickness
    center = toKiCADPoint((origin[0], origin[1])) + toKiCADPoint((normal[0], normal[1]))
    start = origin
    end = center + toKiCADPoint((direction[0], direction[1]))
    # addLine(board, end, end + normal / 2, thickness)
    addRoundedCorner(board, center, start, end, thickness)

def numberOfCuts(length, bridgeWidth, bridgeSpacing):
    """
    Return number of bridges which fit inside the length and cut length
    """
    count = int(np.floor((length + bridgeWidth) / (bridgeWidth + bridgeSpacing)))
    cutLength = (length - (count - 1) * bridgeWidth) / count
    return count, cutLength

def addFrame(board, rect, bridgeWidth, bridgeSpacing, clearance):
    """
    Add rectangular frame to the board
    """
    R=fromMm(1)

    corners = [
        (tl(rect), toKiCADPoint((R, 0)), toKiCADPoint((0, R))), # TL
        (tr(rect), toKiCADPoint((0, R)), toKiCADPoint((-R, 0))), # TR
        (br(rect), toKiCADPoint((-R, 0)), toKiCADPoint((0, -R))), # BR
        (bl(rect), toKiCADPoint((0, -R)), toKiCADPoint((R, 0))) # BL
    ]
    for c, sOffset, eOffset in corners:
        addRoundedCorner(board, c + sOffset + eOffset, c + sOffset, c + eOffset, clearance)

    count, cutLength = numberOfCuts(rect.GetWidth() - 2 * R, bridgeWidth, bridgeSpacing)
    for i in range(count):
        start = rect.GetX() + R + i * bridgeWidth + i * cutLength
        end = start + cutLength

        y1, y2 = rect.GetY(), rect.GetY() + rect.GetHeight()
        addLine(board, toKiCADPoint((start, y1)), toKiCADPoint((end, y1)), clearance)
        if i != 0:
            addBite(board, toKiCADPoint((start, y1)), toKiCADPoint((-1, 0)), toKiCADPoint((0, 1)), clearance)
        if i != count - 1:
            addBite(board, toKiCADPoint((end, y1)), toKiCADPoint((1, 0)), toKiCADPoint((0, 1)), clearance)
        addLine(board, toKiCADPoint((start, y2)), toKiCADPoint((end, y2)), clearance)
        if i != 0:
            addBite(board, toKiCADPoint((start, y2)), toKiCADPoint((-1, 0)), toKiCADPoint((0, -1)), clearance)
        if i != count - 1:
            addBite(board, toKiCADPoint((end, y2)), toKiCADPoint((1, 0)), toKiCADPoint((0, -1)), clearance)

    count, cutLength = numberOfCuts(rect.GetHeight() - 2 * R, bridgeWidth, bridgeSpacing)
    for i in range(count):
        start = rect.GetY() + R + i * bridgeWidth + i * cutLength
        end = start + cutLength

        x1, x2 = rect.GetX(), rect.GetX() + rect.GetWidth()
        addLine(board, toKiCADPoint((x1, start)), toKiCADPoint((x1, end)), clearance)
        if i != 0:
            addBite(board, toKiCADPoint((x1, start)), toKiCADPoint((0, -1)), toKiCADPoint((1, 0)), clearance)
        if i != count - 1:
            addBite(board, toKiCADPoint((x1, end)), toKiCADPoint((0, 1)), toKiCADPoint((1, 0)), clearance)
        addLine(board, toKiCADPoint((x2, start)), toKiCADPoint((x2, end)), clearance)
        if i != 0:
            addBite(board, toKiCADPoint((x2, start)), toKiCADPoint((0, -1)), toKiCADPoint((-1, 0)), clearance)
        if i != count - 1:
            addBite(board, toKiCADPoint((x2, end)), toKiCADPoint((0, 1)), toKiCADPoint((-1, 0)), clearance)

def addHole(board, position, radius):
    circle = pcbnew.PCB_SHAPE()
    circle.SetShape(STROKE_T.S_CIRCLE)
    circle.SetCenter(toKiCADPoint((position[0], position[1])))
    # Set 3'oclock point of the circle to set radius
    circle.SetEnd(toKiCADPoint((position[0], position[1])) + toKiCADPoint((radius/2, 0)))

    circle.SetWidth(radius)
    circle.SetLayer(Layer.F_Paste)
    board.Add(circle)
    addBottomCounterpart(board, circle)

def addJigFrame(board, jigFrameSize, bridgeWidth=fromMm(2),
                bridgeSpacing=fromMm(10), clearance=fromMm(0.5)):
    """
    Given a Pcbnew board finds the board outline and creates a stencil for
    KiKit's stencil jig.

    Mainly, adds mounting holes and mouse bites to define the panel outline.

    jigFrameSize is a tuple (width, height).
    """
    bBox = findBoardBoundingBox(board)
    frameSize = rectByCenter(rectCenter(bBox),
        jigFrameSize[0] + 2 * (OUTER_BORDER + INNER_BORDER),
        jigFrameSize[1] + 2 * (OUTER_BORDER + INNER_BORDER))
    cutSize = rectByCenter(rectCenter(bBox),
        jigFrameSize[0] + 2 * (OUTER_BORDER + INNER_BORDER) - fromMm(1),
        jigFrameSize[1] + 2 * (OUTER_BORDER + INNER_BORDER) - fromMm(1))
    addFrame(board, cutSize, bridgeWidth, bridgeSpacing, clearance)

    for i in range(MOUNTING_HOLES_COUNT):
        x = frameSize.GetX() + OUTER_BORDER / 2 + (i + 1) * (frameSize.GetWidth() - OUTER_BORDER) / (MOUNTING_HOLES_COUNT + 1)
        addHole(board, toKiCADPoint((x, OUTER_BORDER / 2 + frameSize.GetY())), MOUNTING_HOLE_R)
        addHole(board, toKiCADPoint((x, - OUTER_BORDER / 2 +frameSize.GetY() + frameSize.GetHeight())), MOUNTING_HOLE_R)
    for i in range(MOUNTING_HOLES_COUNT):
        y = frameSize.GetY() + OUTER_BORDER / 2 + (i + 1) * (frameSize.GetHeight() - OUTER_BORDER) / (MOUNTING_HOLES_COUNT + 1)
        addHole(board, toKiCADPoint((OUTER_BORDER / 2 + frameSize.GetX(), y)), MOUNTING_HOLE_R)
        addHole(board, toKiCADPoint((- OUTER_BORDER / 2 +frameSize.GetX() + frameSize.GetWidth(), y)), MOUNTING_HOLE_R)

    PIN_TOLERANCE = fromMm(0.05)
    addHole(board, tl(frameSize) + toKiCADPoint((OUTER_BORDER / 2, OUTER_BORDER / 2)), MOUNTING_HOLE_R + PIN_TOLERANCE)
    addHole(board, tr(frameSize) + toKiCADPoint((-OUTER_BORDER / 2, OUTER_BORDER / 2)), MOUNTING_HOLE_R + PIN_TOLERANCE)
    addHole(board, br(frameSize) + toKiCADPoint((-OUTER_BORDER / 2, -OUTER_BORDER / 2)), MOUNTING_HOLE_R + PIN_TOLERANCE)
    addHole(board, bl(frameSize) + toKiCADPoint((OUTER_BORDER / 2, -OUTER_BORDER / 2)), MOUNTING_HOLE_R + PIN_TOLERANCE)
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

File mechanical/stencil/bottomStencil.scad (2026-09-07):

// Generated by SolidPython 1.1.3 on 2026-08-31 20:26:12
$fa = 0.4; $fs = 0.4;


rotate(a = 0, v = [1, 0, 0]) {
	difference() {
		scale(v = [1, 1, 1]) {
			difference() {
				linear_extrude(height = 1.5000000000) {
					offset(r = 1.6000000000) {
						import(file = "/home/thebu/newhome/softek/pico2-knob/mechanical/stencil/pico2-knob-EdgeCuts.dxf", origin = [0, 0]);
					}
				}
				translate(v = [0, 0, 0.2000000000]) {
					linear_extrude(height = 1.5000000000) {
						offset(r = 0.1000000000) {
							import(file = "/home/thebu/newhome/softek/pico2-knob/mechanical/stencil/pico2-knob-EdgeCuts.dxf", origin = [0, 0]);
						}
					}
				}
			}
		}
		linear_extrude(center = true, height = 0.8000000000) {
			translate(v = [0, 0, 0]) {
				import(file = "/home/thebu/newhome/softek/pico2-knob/mechanical/stencil/pico2-knob-PasteBottom.dxf", origin = [0, 0]);
			}
		}
	}
}
/***********************************************
*********      SolidPython code:      **********
************************************************
 
import pcbnew
import numpy as np
import json
from collections import OrderedDict
from kikit.common import *
from kikit.defs import *
from kikit.substrate import Substrate, extractRings, toShapely, linestringToKicad
from kikit.export import gerberImpl, pasteDxfExport
from kikit.export import exportSettingsJlcpcb
import solid
import solid.utils
import subprocess
import shutil
from kikit.common import removeComponents, parseReferences

from shapely.geometry import Point


OUTER_BORDER = fromMm(7.5)
INNER_BORDER = fromMm(5)
MOUNTING_HOLES_COUNT = 3
MOUNTING_HOLE_R = fromMm(1)
HOLE_SPACING = fromMm(20)

def addBottomCounterpart(board, item):
    item = item.Duplicate()
    item.SetLayer(Layer.B_Paste)
    board.Add(item)

def addRoundedCorner(board, center, start, end, thickness):
    corner = pcbnew.PCB_SHAPE()
    corner.SetShape(STROKE_T.S_ARC)
    corner.SetCenter(toKiCADPoint((center[0], center[1])))
    corner.SetStart(toKiCADPoint((start[0], start[1])))

    startVector = start - center
    endVector = end - center
    if startVector[0] * endVector[1] - startVector[1] * endVector[0] > 0:
        corner.SetArcAngleAndEnd(fromDegrees(90), True)
    else:
        corner.SetArcAngleAndEnd(fromDegrees(-90), True)
    corner.SetWidth(thickness)
    corner.SetLayer(Layer.F_Paste)
    board.Add(corner)
    addBottomCounterpart(board, corner)

def addLine(board, start, end, thickness):
    line = pcbnew.PCB_SHAPE()
    line.SetShape(STROKE_T.S_SEGMENT)
    line.SetStart(toKiCADPoint((start[0], start[1])))
    line.SetEnd(toKiCADPoint((end[0], end[1])))
    line.SetWidth(thickness)
    line.SetLayer(Layer.F_Paste)
    board.Add(line)
    addBottomCounterpart(board, line)

def addBite(board, origin, direction, normal, thickness):
    """
    Adds a bite to the stencil, direction points to the bridge, normal points
    inside the stencil
    """
    direction = normalize(direction) * thickness
    normal = normalize(normal) * thickness
    center = toKiCADPoint((origin[0], origin[1])) + toKiCADPoint((normal[0], normal[1]))
    start = origin
    end = center + toKiCADPoint((direction[0], direction[1]))
    # addLine(board, end, end + normal / 2, thickness)
    addRoundedCorner(board, center, start, end, thickness)

def numberOfCuts(length, bridgeWidth, bridgeSpacing):
    """
    Return number of bridges which fit inside the length and cut length
    """
    count = int(np.floor((length + bridgeWidth) / (bridgeWidth + bridgeSpacing)))
    cutLength = (length - (count - 1) * bridgeWidth) / count
    return count, cutLength

def addFrame(board, rect, bridgeWidth, bridgeSpacing, clearance):
    """
    Add rectangular frame to the board
    """
    R=fromMm(1)

    corners = [
        (tl(rect), toKiCADPoint((R, 0)), toKiCADPoint((0, R))), # TL
        (tr(rect), toKiCADPoint((0, R)), toKiCADPoint((-R, 0))), # TR
        (br(rect), toKiCADPoint((-R, 0)), toKiCADPoint((0, -R))), # BR
        (bl(rect), toKiCADPoint((0, -R)), toKiCADPoint((R, 0))) # BL
    ]
    for c, sOffset, eOffset in corners:
        addRoundedCorner(board, c + sOffset + eOffset, c + sOffset, c + eOffset, clearance)

    count, cutLength = numberOfCuts(rect.GetWidth() - 2 * R, bridgeWidth, bridgeSpacing)
    for i in range(count):
        start = rect.GetX() + R + i * bridgeWidth + i * cutLength
        end = start + cutLength

        y1, y2 = rect.GetY(), rect.GetY() + rect.GetHeight()
        addLine(board, toKiCADPoint((start, y1)), toKiCADPoint((end, y1)), clearance)
        if i != 0:
            addBite(board, toKiCADPoint((start, y1)), toKiCADPoint((-1, 0)), toKiCADPoint((0, 1)), clearance)
        if i != count - 1:
            addBite(board, toKiCADPoint((end, y1)), toKiCADPoint((1, 0)), toKiCADPoint((0, 1)), clearance)
        addLine(board, toKiCADPoint((start, y2)), toKiCADPoint((end, y2)), clearance)
        if i != 0:
            addBite(board, toKiCADPoint((start, y2)), toKiCADPoint((-1, 0)), toKiCADPoint((0, -1)), clearance)
        if i != count - 1:
            addBite(board, toKiCADPoint((end, y2)), toKiCADPoint((1, 0)), toKiCADPoint((0, -1)), clearance)

    count, cutLength = numberOfCuts(rect.GetHeight() - 2 * R, bridgeWidth, bridgeSpacing)
    for i in range(count):
        start = rect.GetY() + R + i * bridgeWidth + i * cutLength
        end = start + cutLength

        x1, x2 = rect.GetX(), rect.GetX() + rect.GetWidth()
        addLine(board, toKiCADPoint((x1, start)), toKiCADPoint((x1, end)), clearance)
        if i != 0:
            addBite(board, toKiCADPoint((x1, start)), toKiCADPoint((0, -1)), toKiCADPoint((1, 0)), clearance)
        if i != count - 1:
            addBite(board, toKiCADPoint((x1, end)), toKiCADPoint((0, 1)), toKiCADPoint((1, 0)), clearance)
        addLine(board, toKiCADPoint((x2, start)), toKiCADPoint((x2, end)), clearance)
        if i != 0:
            addBite(board, toKiCADPoint((x2, start)), toKiCADPoint((0, -1)), toKiCADPoint((-1, 0)), clearance)
        if i != count - 1:
            addBite(board, toKiCADPoint((x2, end)), toKiCADPoint((0, 1)), toKiCADPoint((-1, 0)), clearance)

def addHole(board, position, radius):
    circle = pcbnew.PCB_SHAPE()
    circle.SetShape(STROKE_T.S_CIRCLE)
    circle.SetCenter(toKiCADPoint((position[0], position[1])))
    # Set 3'oclock point of the circle to set radius
    circle.SetEnd(toKiCADPoint((position[0], position[1])) + toKiCADPoint((radius/2, 0)))

    circle.SetWidth(radius)
    circle.SetLayer(Layer.F_Paste)
    board.Add(circle)
    addBottomCounterpart(board, circle)

def addJigFrame(board, jigFrameSize, bridgeWidth=fromMm(2),
                bridgeSpacing=fromMm(10), clearance=fromMm(0.5)):
    """
    Given a Pcbnew board finds the board outline and creates a stencil for
    KiKit's stencil jig.

    Mainly, adds mounting holes and mouse bites to define the panel outline.

    jigFrameSize is a tuple (width, height).
    """
    bBox = findBoardBoundingBox(board)
    frameSize = rectByCenter(rectCenter(bBox),
        jigFrameSize[0] + 2 * (OUTER_BORDER + INNER_BORDER),
        jigFrameSize[1] + 2 * (OUTER_BORDER + INNER_BORDER))
    cutSize = rectByCenter(rectCenter(bBox),
        jigFrameSize[0] + 2 * (OUTER_BORDER + INNER_BORDER) - fromMm(1),
        jigFrameSize[1] + 2 * (OUTER_BORDER + INNER_BORDER) - fromMm(1))
    addFrame(board, cutSize, bridgeWidth, bridgeSpacing, clearance)

    for i in range(MOUNTING_HOLES_COUNT):
        x = frameSize.GetX() + OUTER_BORDER / 2 + (i + 1) * (frameSize.GetWidth() - OUTER_BORDER) / (MOUNTING_HOLES_COUNT + 1)
        addHole(board, toKiCADPoint((x, OUTER_BORDER / 2 + frameSize.GetY())), MOUNTING_HOLE_R)
        addHole(board, toKiCADPoint((x, - OUTER_BORDER / 2 +frameSize.GetY() + frameSize.GetHeight())), MOUNTING_HOLE_R)
    for i in range(MOUNTING_HOLES_COUNT):
        y = frameSize.GetY() + OUTER_BORDER / 2 + (i + 1) * (frameSize.GetHeight() - OUTER_BORDER) / (MOUNTING_HOLES_COUNT + 1)
        addHole(board, toKiCADPoint((OUTER_BORDER / 2 + frameSize.GetX(), y)), MOUNTING_HOLE_R)
        addHole(board, toKiCADPoint((- OUTER_BORDER / 2 +frameSize.GetX() + frameSize.GetWidth(), y)), MOUNTING_HOLE_R)

    PIN_TOLERANCE = fromMm(0.05)
    addHole(board, tl(frameSize) + toKiCADPoint((OUTER_BORDER / 2, OUTER_BORDER / 2)), MOUNTING_HOLE_R + PIN_TOLERANCE)
    addHole(board, tr(frameSize) + toKiCADPoint((-OUTER_BORDER / 2, OUTER_BORDER / 2)), MOUNTING_HOLE_R + PIN_TOLERANCE)
    addHole(board, br(frameSize) + toKiCADPoint((-OUTER_BORDER / 2, -OUTER_BORDER / 2)), MOUNTING_HOLE_R + PIN_TOLERANCE)
    addHole(board, bl(frameSize) + toKiCADPoint((OUTER_BORDER / 2, -OUTER_BORDER / 2)), MOUNTING_HOLE_R + PIN_TOLERANCE)
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

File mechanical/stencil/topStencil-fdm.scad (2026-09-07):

// Generated by SolidPython 1.1.3 on 2026-08-31 21:13:47
$fa = 0.4; $fs = 0.4;


rotate(a = 180, v = [1, 0, 0]) {
	difference() {
		scale(v = [1, 1, -1]) {
			difference() {
				linear_extrude(height = 1.5000000000) {
					offset(r = 1.6000000000) {
						import(file = "/home/thebu/newhome/softek/pico2-knob/mechanical/stencil/pico2-knob-EdgeCuts.dxf", origin = [0, 0]);
					}
				}
				translate(v = [0, 0, 0.2000000000]) {
					linear_extrude(height = 1.5000000000) {
						offset(r = 0.1000000000) {
							import(file = "/home/thebu/newhome/softek/pico2-knob/mechanical/stencil/pico2-knob-EdgeCuts.dxf", origin = [0, 0]);
						}
					}
				}
			}
		}
		linear_extrude(center = true, height = 0.8000000000) {
			offset(chamfer = false, delta = 0.0500000000) {
				import(file = "/home/thebu/newhome/softek/pico2-knob/mechanical/stencil/pico2-knob-PasteTop.dxf", origin = [0, 0]);
			}
		}
	}
}
/***********************************************
*********      SolidPython code:      **********
************************************************
 
import pcbnew
import numpy as np
import json
from collections import OrderedDict
from kikit.common import *
from kikit.defs import *
from kikit.substrate import Substrate, extractRings, toShapely, linestringToKicad
from kikit.export import gerberImpl, pasteDxfExport
from kikit.export import exportSettingsJlcpcb
import solid
import solid.utils
import subprocess
import shutil
from kikit.common import removeComponents, parseReferences

from shapely.geometry import Point


OUTER_BORDER = fromMm(7.5)
INNER_BORDER = fromMm(5)
MOUNTING_HOLES_COUNT = 3
MOUNTING_HOLE_R = fromMm(1)
HOLE_SPACING = fromMm(20)

def addBottomCounterpart(board, item):
    item = item.Duplicate()
    item.SetLayer(Layer.B_Paste)
    board.Add(item)

def addRoundedCorner(board, center, start, end, thickness):
    corner = pcbnew.PCB_SHAPE()
    corner.SetShape(STROKE_T.S_ARC)
    corner.SetCenter(toKiCADPoint((center[0], center[1])))
    corner.SetStart(toKiCADPoint((start[0], start[1])))

    startVector = start - center
    endVector = end - center
    if startVector[0] * endVector[1] - startVector[1] * endVector[0] > 0:
        corner.SetArcAngleAndEnd(fromDegrees(90), True)
    else:
        corner.SetArcAngleAndEnd(fromDegrees(-90), True)
    corner.SetWidth(thickness)
    corner.SetLayer(Layer.F_Paste)
    board.Add(corner)
    addBottomCounterpart(board, corner)

def addLine(board, start, end, thickness):
    line = pcbnew.PCB_SHAPE()
    line.SetShape(STROKE_T.S_SEGMENT)
    line.SetStart(toKiCADPoint((start[0], start[1])))
    line.SetEnd(toKiCADPoint((end[0], end[1])))
    line.SetWidth(thickness)
    line.SetLayer(Layer.F_Paste)
    board.Add(line)
    addBottomCounterpart(board, line)

def addBite(board, origin, direction, normal, thickness):
    """
    Adds a bite to the stencil, direction points to the bridge, normal points
    inside the stencil
    """
    direction = normalize(direction) * thickness
    normal = normalize(normal) * thickness
    center = toKiCADPoint((origin[0], origin[1])) + toKiCADPoint((normal[0], normal[1]))
    start = origin
    end = center + toKiCADPoint((direction[0], direction[1]))
    # addLine(board, end, end + normal / 2, thickness)
    addRoundedCorner(board, center, start, end, thickness)

def numberOfCuts(length, bridgeWidth, bridgeSpacing):
    """
    Return number of bridges which fit inside the length and cut length
    """
    count = int(np.floor((length + bridgeWidth) / (bridgeWidth + bridgeSpacing)))
    cutLength = (length - (count - 1) * bridgeWidth) / count
    return count, cutLength

def addFrame(board, rect, bridgeWidth, bridgeSpacing, clearance):
    """
    Add rectangular frame to the board
    """
    R=fromMm(1)
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

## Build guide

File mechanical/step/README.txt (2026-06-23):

drop STEP files here, named as below:
nicenano.step   - nice!nano v2 (or clone)
encoder.step    - EC11 rotary encoder
button.step     - tactile button (I'll instance it x3)
oled.step        - optional, if you find one for the 0.87" module

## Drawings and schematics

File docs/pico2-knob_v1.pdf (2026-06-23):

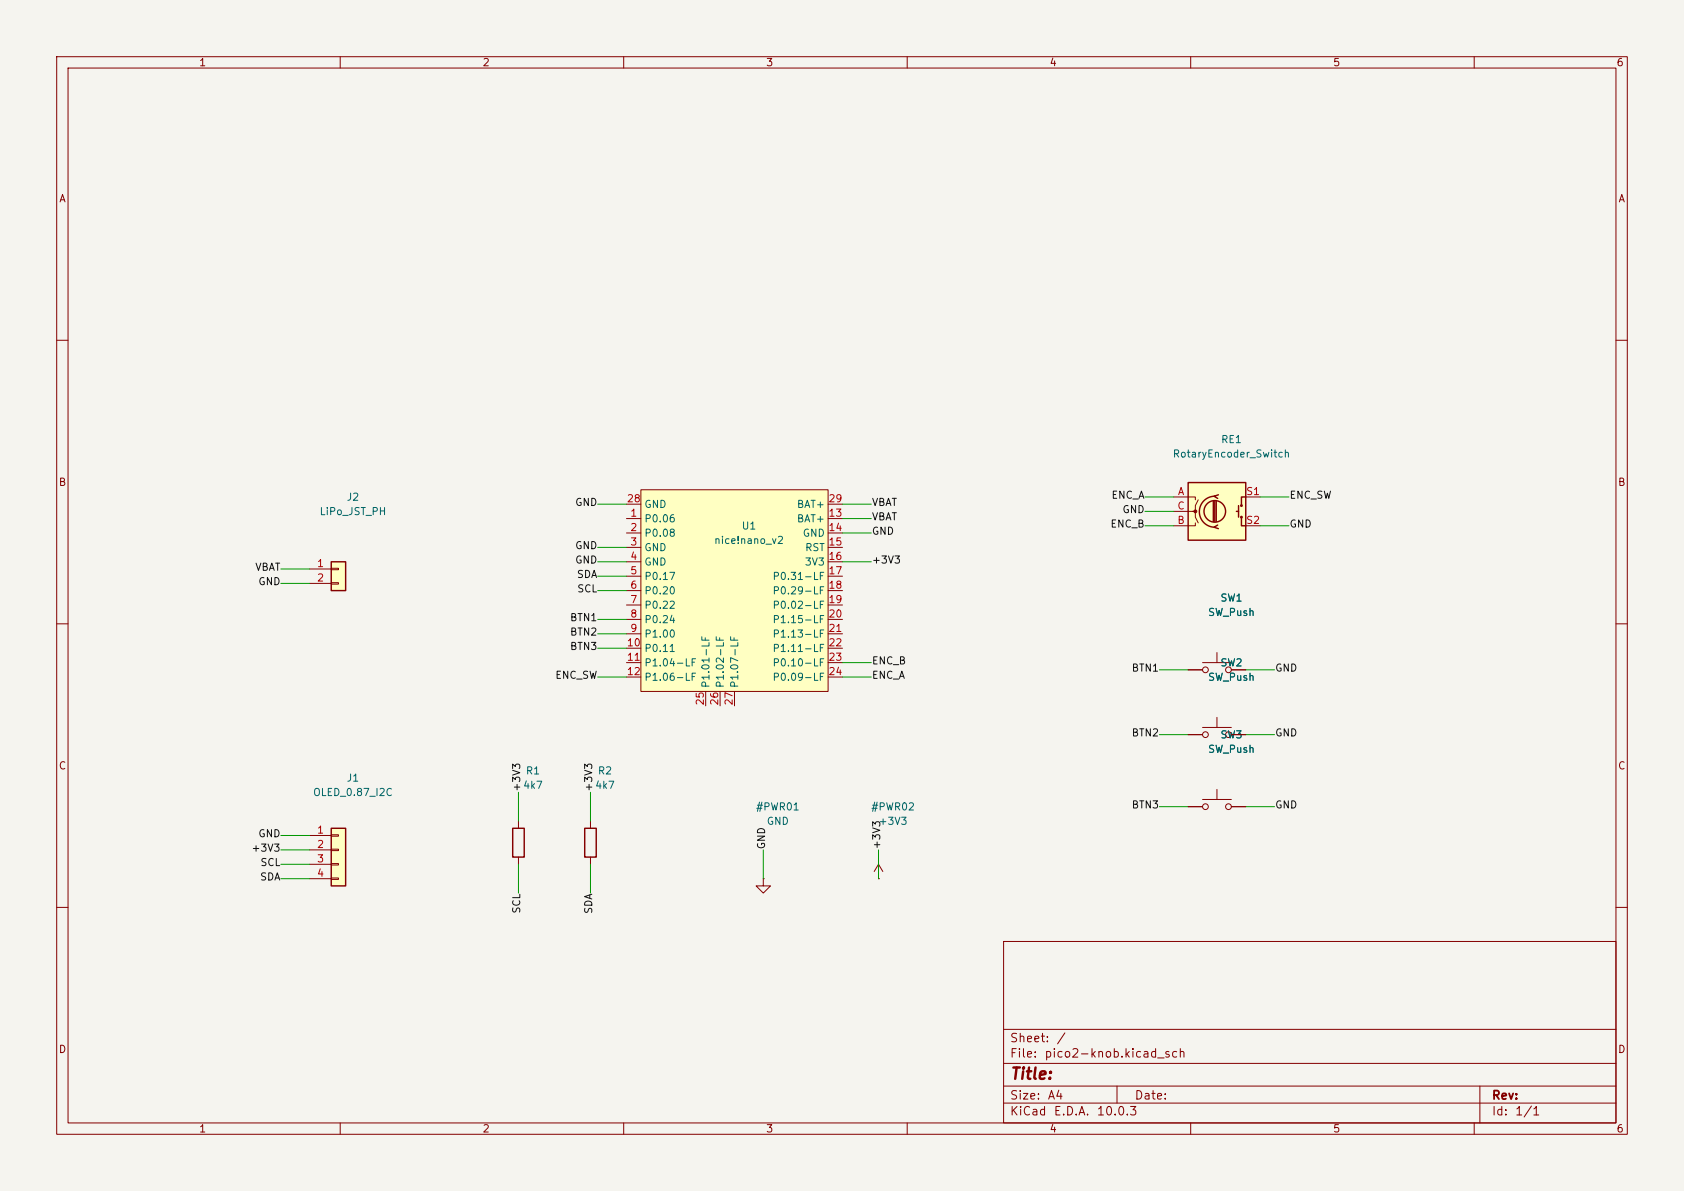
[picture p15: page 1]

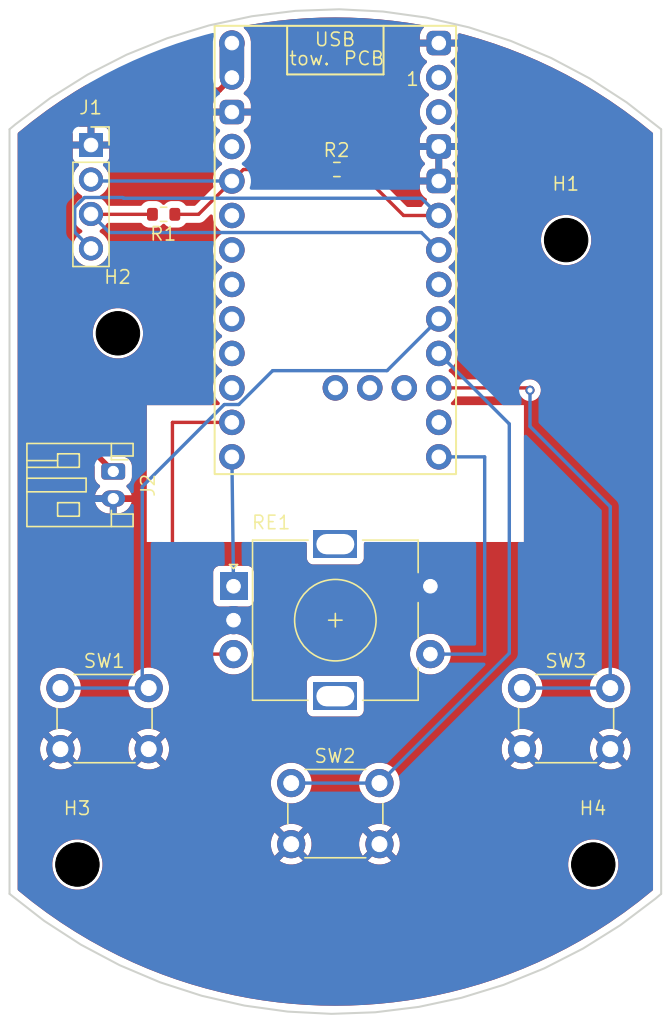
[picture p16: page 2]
D Date:; KiCad E.D.A. 10.0.3; Size: A4; Rev:; Title:; File: pico2-knob.kicad_pcb; Sheet:; RE1 USB; tow. PCB

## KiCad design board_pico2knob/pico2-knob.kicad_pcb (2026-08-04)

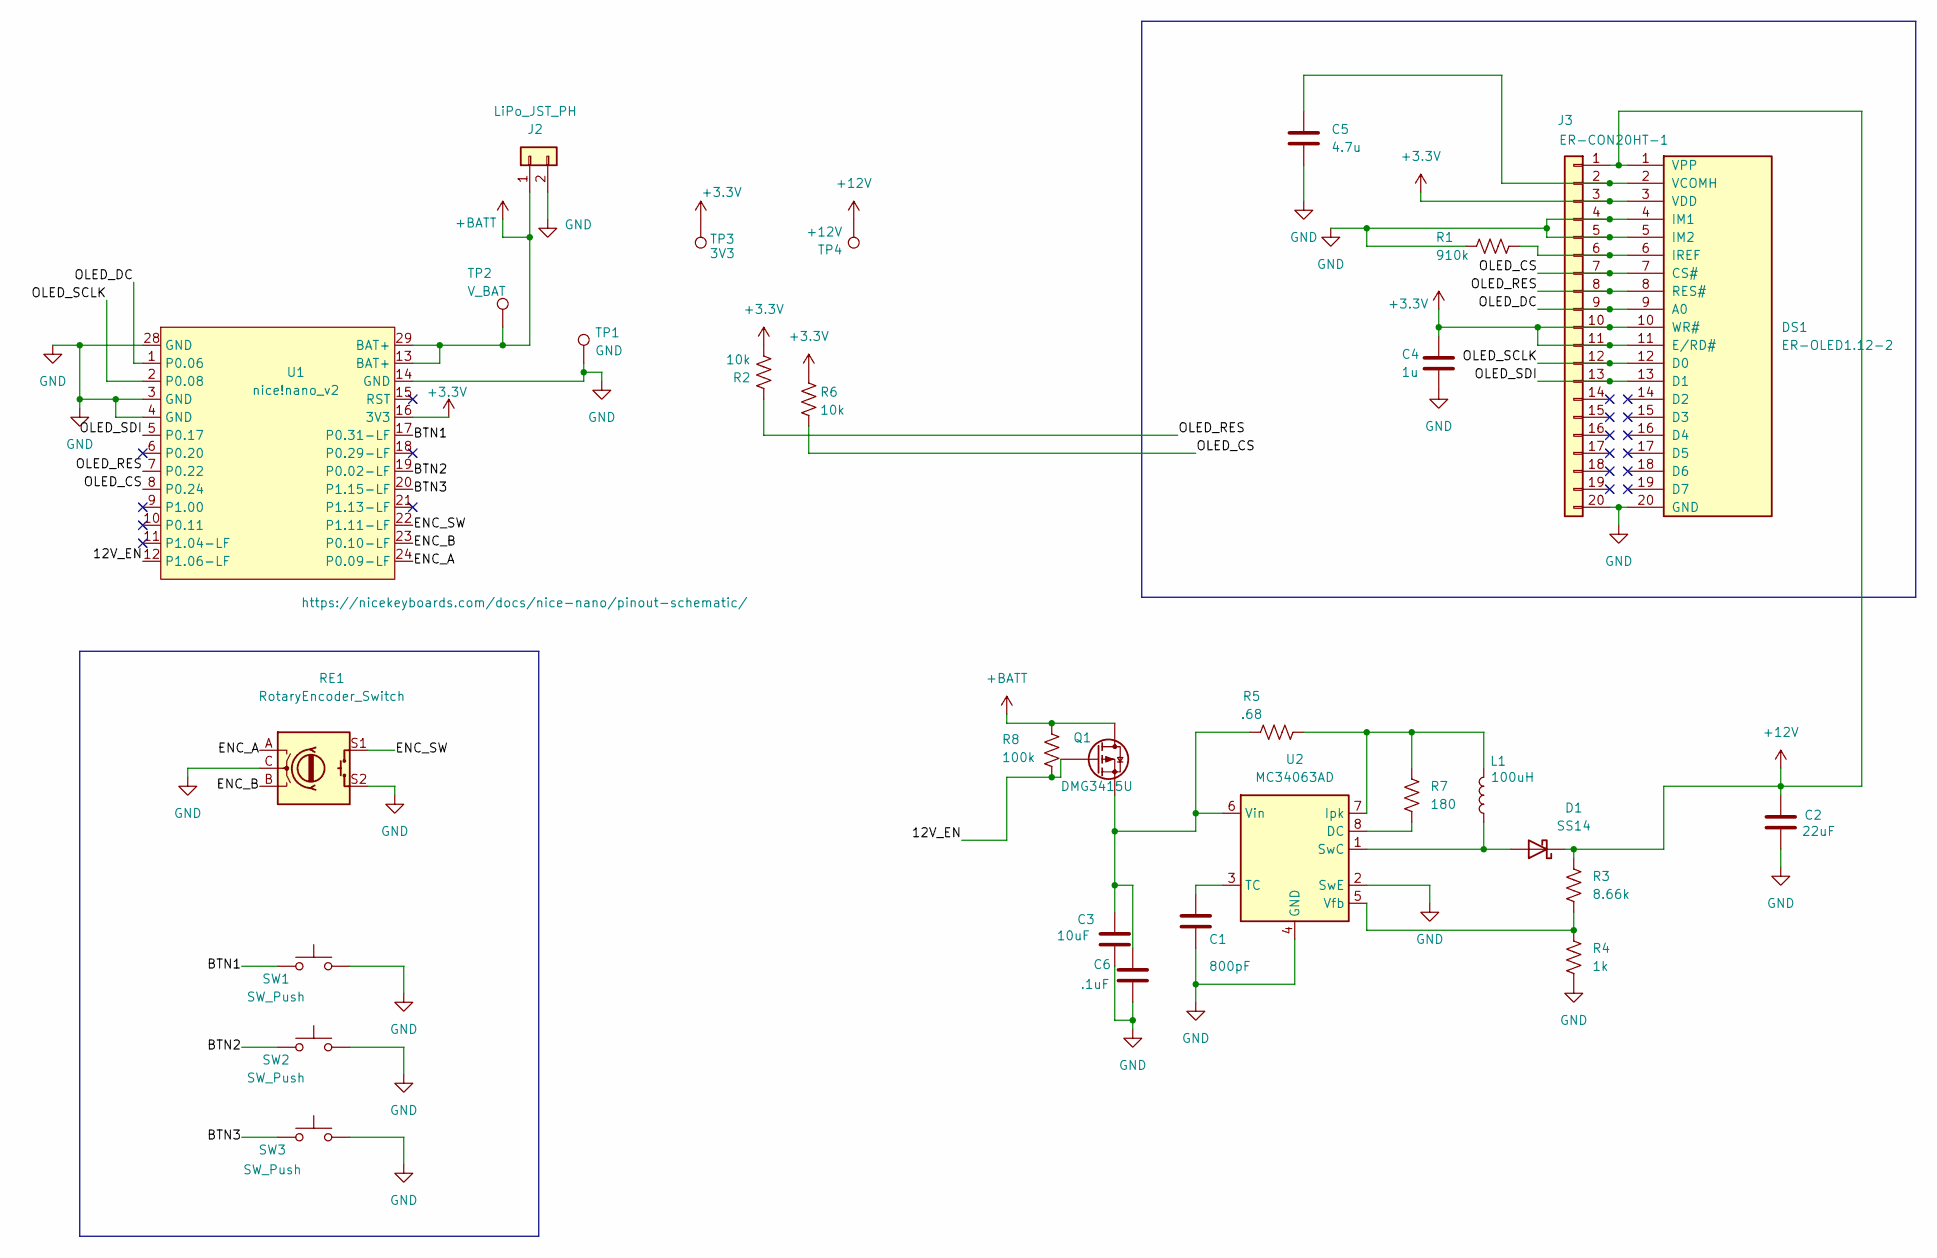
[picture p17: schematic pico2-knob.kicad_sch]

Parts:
C1: 800pF; C_1206_3216Metric; MFRPN CC1206KRX7R9BB681
C2: 22uF; C_1210_3225Metric; MFRPN GRM32ER61E226KE15L
C3: 10uF; C_1206_3216Metric; MFRPN GRM31CR61E106KA12L
C4: 1u; C_1206_3216Metric; MFRPN CL31B105KBHNNNE
C5: 4.7u; C_1206_3216Metric; MFRPN GRM31CR61E475KA12L
C6: .1uF; C_1206_3216Metric; MFRPN GRM31CR61E106KA12L
D1: SS14; D_SMA; MFRPN SS14-E3/61T
DS1: ER-OLED1.12-2; MFRPN ER-OLED1.12-2W
J2: LiPo_JST_PH; JST_PH_S2B-PH-K_1x02_P2.00mm_Horizontal; MFRPN S2B-PH-K-S
J3: ER-CON20HT-1; MFRPN ER-CON20HT-1
L1: 100uH; L_12x12mm_H6mm; MFRPN SRR1260-101M
Q1: DMG3415U; SOT-23; MFRPN DMG3415U-7
R1: 910k; R_Axial_DIN0207_L6.3mm_D2.5mm_P7.62mm_Horizontal; MFRPN MFR-25FBF52-910K
R2, R6: 10k; R_Axial_DIN0207_L6.3mm_D2.5mm_P7.62mm_Horizontal; MFRPN MFR-25FBF52-10K
R3: 8.66k; R_Axial_DIN0207_L6.3mm_D2.5mm_P7.62mm_Horizontal; MFRPN CFR-25JB-52-R68
R4: 1k; R_Axial_DIN0207_L6.3mm_D2.5mm_P7.62mm_Horizontal; MFRPN MFR-25FBF52-1K
R5: .68; R_Axial_DIN0207_L6.3mm_D2.5mm_P7.62mm_Horizontal; MFRPN MFR-25FBF52-8K66
R7: 180; R_Axial_DIN0207_L6.3mm_D2.5mm_P7.62mm_Horizontal; MFRPN CFR-25JB-52-R68
R8: 100k; R_Axial_DIN0207_L6.3mm_D2.5mm_P7.62mm_Horizontal; MFRPN CFR-25JB-52-R68
RE1: RotaryEncoder_Switch; RotaryEncoder_Alps_EC11E-Switch_Vertical_H20mm; MFRPN EC11E15244G1
SW1, SW2, SW3: SW_Push; SW_PUSH_6mm; MFRPN SKHHAKA010
TP1: GND; TestPoint_Pad_D1.5mm
TP2: V_BAT; TestPoint_Pad_D1.5mm
TP3: 3V3; TestPoint_Pad_D1.5mm
TP4: +12V; TestPoint_Pad_D1.5mm
U1: nice!nano_v2; nice_nano_AH_Reversible; MFRPN nice!nano_v2
U2: MC34063AD; SOIC-8_3.9x4.9mm_P1.27mm; MFRPN MC34063ADR2G

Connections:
+3.3V: C4.2, DS1.3 (VDD), DS1.10 (WR#), DS1.11 (E/RD#), J3.3, J3.10, J3.11, R2.1, R6.1, TP3.1 (1_1), U1.16 (3V3)
+12V: C2.1, D1.1 (K), DS1.1 (VPP), J3.1, R3.1, TP4.1 (1_1)
+BATT: J2.1, Q1.D, R8.1, TP2.1 (1_1), U1.13 (BAT+), U1.29 (BAT+)
/12V_EN: Q1.G, R8.2, U1.12 (P1.06-LF)
/BTN1: SW1.1, U1.17 (P0.31-LF)
/BTN2: SW2.1, U1.19 (P0.02-LF)
/BTN3: SW3.1, U1.20 (P1.15-LF)
/ENC_A: RE1.A, U1.24 (P0.09-LF)
/ENC_B: RE1.B, U1.23 (P0.10-LF)
/ENC_SW: RE1.S1, U1.22 (P1.11-LF)
/OLED_CS: DS1.7 (CS#), J3.7, R6.2, U1.8 (P0.24)
/OLED_DC: DS1.9 (A0), J3.9, U1.1 (P0.06)
/OLED_RES: DS1.8 (RES#), J3.8, R2.2, U1.7 (P0.22)
/OLED_SCLK: DS1.12 (D0), J3.12, U1.2 (P0.08)
/OLED_SDI: DS1.13 (D1), J3.13, U1.5 (P0.17)
GND: C1.2, C2.2, C3.2, C4.1, C5.2, C6.2, DS1.4 (IM1), DS1.5 (IM2), DS1.20 (GND), J2.2, J3.4, J3.5, J3.20, R1.2, R4.2, RE1.C, RE1.S2, SW1.2, SW2.2, SW3.2, TP1.1 (1_1), U1.3 (GND), U1.4 (GND), U1.14 (GND), U1.28 (GND), U2.2 (SwE), U2.4 (GND)
unnamed: D1.2 (A), L1.1, U2.1 (SwC)
unnamed: C5.1, DS1.2 (VCOMH), J3.2
unnamed: DS1.6 (IREF), J3.6, R1.1
unnamed: R7.2, U2.8 (DC)
unnamed: L1.2, R5.2, R7.1, U2.7 (Ipk)
unnamed: C1.1, U2.3 (TC)
unnamed: R3.2, R4.1, U2.5 (Vfb)
unnamed: C3.1, C6.1, Q1.S, R5.1, U2.6 (Vin)

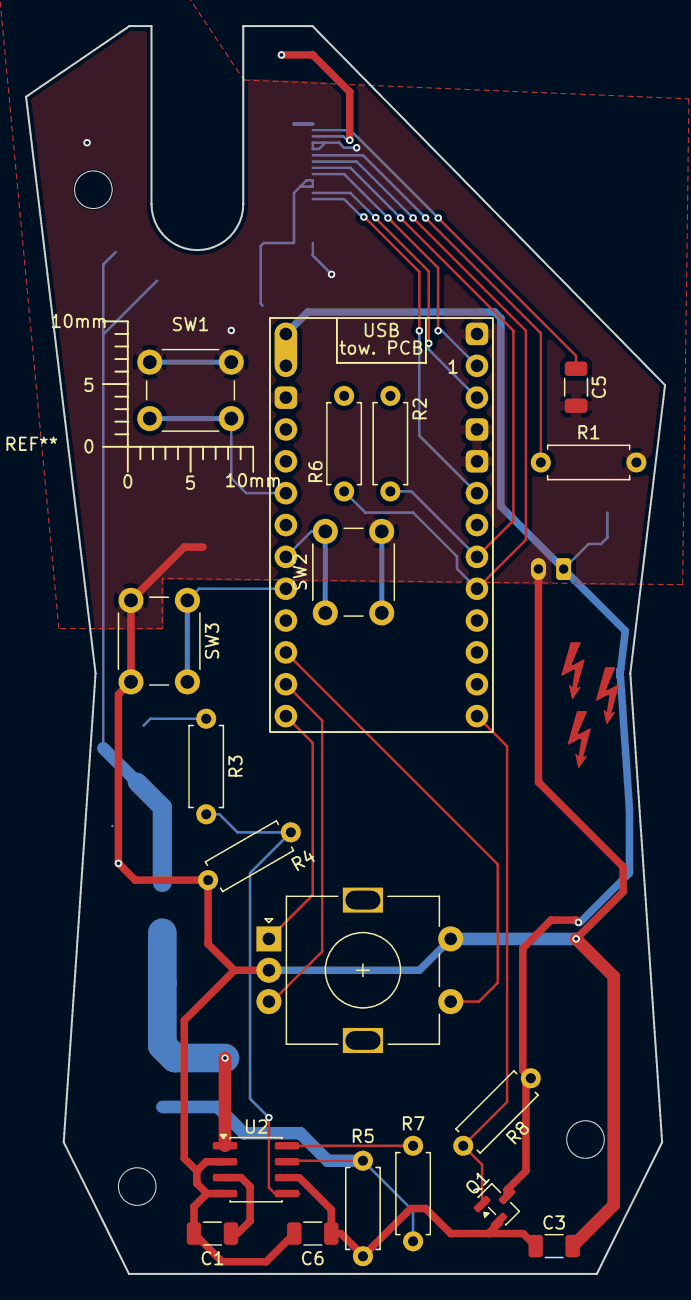
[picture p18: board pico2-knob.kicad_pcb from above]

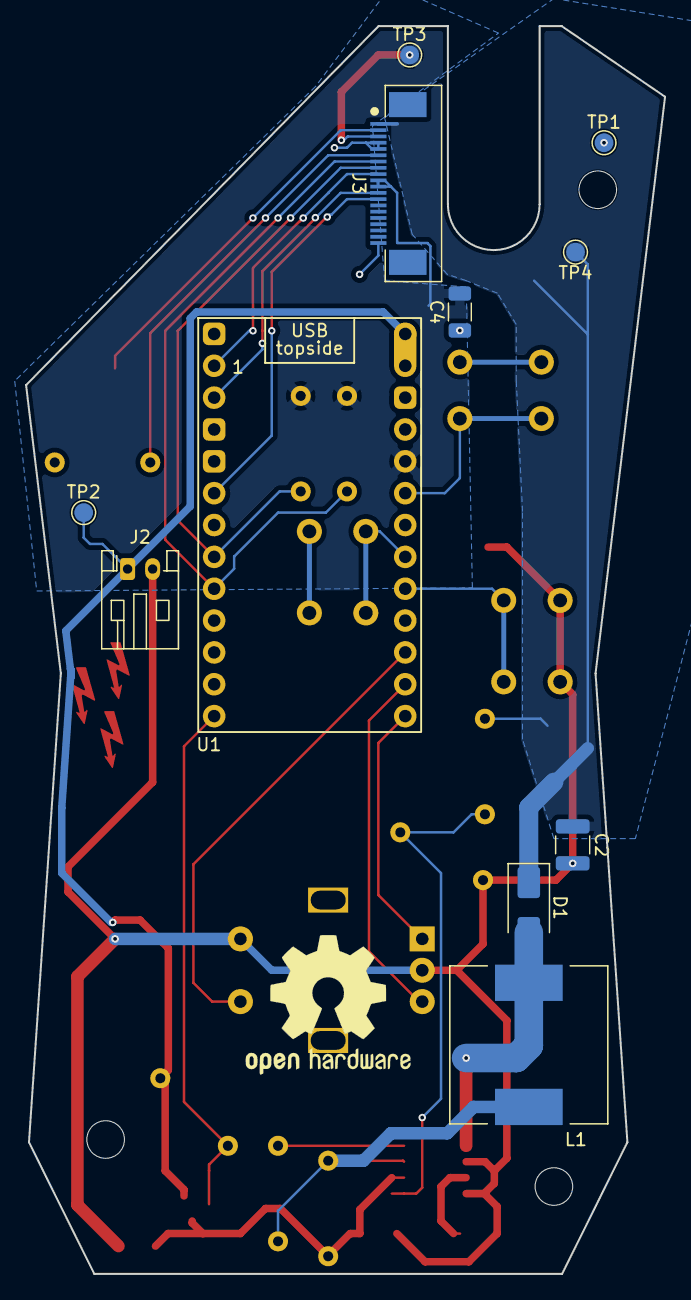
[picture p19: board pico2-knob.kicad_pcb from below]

Board: 2 copper layers, 51.0 x 99.5 mm, 29 parts (11 on the bottom side), 24 nets.

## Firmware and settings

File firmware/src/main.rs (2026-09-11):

//! pico2joy / pico2-knob bring-up firmware.
//!
//! Brings up the nice!nano v2, the encoder, the three buttons and the SH1107
//! ribbon OLED, and streams every input edge over USB serial (CDC-ACM) while
//! mirroring the same state on the screen. No battery support, no BLE.
//!
//! Pinout (nice!nano v2 pads, from `board_pico2knob/pico2-knob.kicad_sch`):
//!
//! | Signal    | nRF52840 | pad | Notes                                       |
//! |-----------|----------|-----|---------------------------------------------|
//! | LED       | P0.15    |  -  | on-module blue LED, active high             |
//! | VCC_EN    | P0.13    |  -  | nice!nano load switch: high = 3V3 pad live  |
//! | ENC_A     | P0.09    | 24  | NFC pin, freed via `nfc-pins-as-gpio`       |
//! | ENC_B     | P0.10    | 23  | likewise                                    |
//! | ENC_SW    | P1.11    | 22  |                                             |
//! | BTN1      | P0.31    | 17  |                                             |
//! | BTN2      | P0.02    | 19  |                                             |
//! | BTN3      | P1.15    | 20  |                                             |
//! | OLED_DC   | P0.06    |  1  | SH1107, 4-wire SPI over the J3 ribbon       |
//! | OLED_SCLK | P0.08    |  2  | SPIM3                                       |
//! | OLED_SDI  | P0.17    |  5  | SPIM3                                       |
//! | OLED_RES  | P0.22    |  7  | 10k pull-up R2: boots out of reset          |
//! | OLED_CS   | P0.24    |  8  | 10k pull-up R6: boots deselected            |
//! | 12V_EN    | P1.06    | 12  | Q1 gate, **active low** - see [`Boost`]     |
//!
//! Switches are all wired to GND, so "pressed" reads low.
//!
//! Four cooperating futures: USB, input polling at 1 kHz, rendering at 25 fps,
//! and the command reader. Log lines go through a channel so a full frame flush
//! never stalls encoder sampling, and so a host that stops reading the port
//! costs us dropped lines rather than missed detents.

#![no_std]
#![no_main]

#[cfg(feature = "ble")]
mod ble;
mod accel;
mod media;
mod cube;
mod display;
mod gantry;
mod quota;
#[cfg(not(feature = "ble"))]
mod radio;
mod state;
mod ui;

use core::cell::RefCell;
use core::fmt::Write as _;
use core::sync::atomic::{AtomicBool, AtomicI32, AtomicU8, AtomicU16, AtomicU32, Ordering};

use embassy_futures::join::{join3, join5};
use embassy_nrf::config::HfclkSource;
use embassy_nrf::gpio::{Flex, Input, Level, Output, OutputDrive, Pull};
use embassy_nrf::pwm::{DutyCycle, SimpleConfig, SimplePwm};
use embassy_nrf::saadc::{self, ChannelConfig, Saadc, VddhDiv5Input};
use embassy_nrf::spim::{self, Spim};
use embassy_nrf::usb::vbus_detect::HardwareVbusDetect;
use embassy_nrf::usb::{self, Driver};
use embassy_nrf::{bind_interrupts, peripherals};
use embassy_sync::blocking_mutex::Mutex;
use embassy_sync::blocking_mutex::raw::CriticalSectionRawMutex;
use embassy_sync::channel::Channel;
use embassy_time::{Duration, Instant, Ticker, Timer, with_timeout};
use embassy_usb::class::cdc_acm::{CdcAcmClass, Sender, State};
use embassy_usb::{Builder, Config};
use heapless::{String, Vec};

use crate::display::Display;

// CLOCK_POWER is one interrupt for two peripherals: USB's VBUS detection lives
// on the POWER half, MPSL's clock management on the CLOCK half. The `ble`
// build hands it to both. It has to: the bootloader leaves the USB events
// enabled and latched, and an interrupt nobody clears is a storm that starves
// everything below it the moment MPSL enables the line. See `ble::ClockGate`.
bind_interrupts!(struct Irqs {
    USBD => usb::InterruptHandler<peripherals::USBD>;
    #[cfg(not(feature = "ble"))]
    CLOCK_POWER => usb::vbus_detect::InterruptHandler;
    #[cfg(feature = "ble")]
    CLOCK_POWER => usb::vbus_detect::InterruptHandler, ble::ClockGate;
    SPIM3 => spim::InterruptHandler<peripherals::SPI3>;
    SAADC => saadc::InterruptHandler;
});

/// Poll interval for switches and the encoder. 1 kHz is far faster than a thumb.
const TICK: Duration = Duration::from_millis(1);
/// Consecutive stable samples (ms) needed to accept a switch edge.
const DEBOUNCE_TICKS: u8 = 4;
/// Two presses of the same button inside this many 1 kHz ticks are a double tap.
const DOUBLE_TAP_TICKS: u32 = 400;
/// Hold a button this long and the step wheel opens under your thumb.
const HOLD_TICKS: u32 = 1000;
/// Weight of the newest detent in the smoothed knob rate. Low enough that a
/// couple of fast clicks don't read as a sustained spin.
const RATE_SMOOTHING: f32 = 0.35;
/// A gap longer than this ends the gesture, and the rate starts from nothing.
const NEW_GESTURE_TICKS: u32 = 400;
/// Heartbeat: a dim 120 ms wink every 5 s. The blue LED is on P0.15 via PWM so
/// "dim" is real dimming, not a shorter blink. (The *red* LED is the LN2054
/// charger's status output - hardware, no GPIO, nothing firmware can do.)
const HEARTBEAT_PERIOD_TICKS: u32 = 5000;
const HEARTBEAT_ON_TICKS: u32 = 120;
/// Out of `SimpleConfig::default()`'s max_duty of 1000, at 1 kHz.
const HEARTBEAT_DUTY: u16 = 30;
const LED_FULL_DUTY: u16 = 1000;
/// Magic the Adafruit UF2 bootloader looks for in GPREGRET, from its `src/main.c`.
/// UF2 gives the mass-storage drive, serial gives CDC-only (what
/// `adafruit-nrfutil dfu serial` wants), and OTA gives BLE DFU - the one that
/// makes a wireless update possible at all. OTA is the "SoftDevice not yet
/// inited" variant, which is us: the SDC is a linked library, not the S140
/// binary in flash.
const DFU_MAGIC_UF2_RESET: u8 = 0x57;
const DFU_MAGIC_SERIAL_ONLY_RESET: u8 = 0x4e;
const DFU_MAGIC_OTA_RESET: u8 = 0xA8;
/// How long the orientation test pattern stays up at boot.
const SPLASH: Duration = Duration::from_millis(1500);

const SWITCH_NAMES: [&str; 4] = ["BTN1", "BTN2", "BTN3", "ENC_SW"];

const HELP: &str = concat!(
    "\r\ncommands: ? help | p pins | d next view (or hold the knob and turn it)\r\n",
    "          i re-init display | f flip 180 | +/- contrast | e 12V rail\r\n",
    "          w wireless | m menu (knob moves, 1/2/3 select, knob press exits)\r\n",
    "          1/2/3 select axis (Z/X/Y, as the buttons do) | , . jog it\r\n",
    "          cube: hold 1/2/3 to spin that axis, knob alone zooms\r\n",
    "          gantry, xcarve: 1/2/3 pick the axis, knob jogs it (needs the bridge)\r\n",
    "          quota: hold a button to re-check the plans | r does it here\r\n",
    "          l led (dark/dim/on) | v verbose | b bootloader (UF2)\r\n",
    "          #r uf2|serial|ota  reboot into a bootloader mode\r\n"
);

/// What a host gets for opening the port.
const GREETING: &str = "\r\npico2joy bring-up (nice!nano v2, embassy)\r\n";

/// Linux hands over every freshly enumerated ttyACM in cooked mode with echo
/// on (`stty -a` on a just-plugged puck says `echo`), and a tty with echo on
/// reflects everything we print straight back into the command parser. The
/// greeting alone spells `p`, `i`, `2` and then `b` - a reboot into the
/// bootloader, which on battery is where it stays until someone reflashes it.
///
/// Three things keep that from happening. Nothing is written unless DTR is
/// up, so no packet sits in the IN endpoint waiting to be delivered (and
/// echoed) during the host's `open()`, before whatever opened it has had the
/// chance to set raw mode. The greeting waits [`GREETING_DELAY`] after DTR
/// rises, which is longer than any tool takes between `open()` and
/// `tcsetattr()`. And for [`ECHO_WINDOW`] after the greeting goes out, keys
/// are held rather than dispatched while the parser watches for its own
/// greeting coming back: [`ECHO_SCORE`] received bytes that occur in this
/// line, in order, is an echo, not a person, and single keys are ignored
/// until the port is reopened. In order but not necessarily adjacent, and
/// never released on a mismatch, because the kernel's echo is lossy - one
/// byte per USB packet, and it drops most of a burst once the write URBs
/// are all in flight - so "pico2joy bring-" followed by fragments is what
/// actually comes back. A person typing in that first second gets their
/// keys when the window closes. `#` lines are never held, since nothing we
/// print can spell one that does harm.
const ECHO_PROBE: &[u8] = GREETING.trim_ascii().as_bytes();
const ECHO_WINDOW: Duration = Duration::from_millis(1000);
const ECHO_SCORE: usize = 4;
const GREETING_DELAY: Duration = Duration::from_millis(100);

type Line = String<192>;

/// Log lines waiting for the USB writer. Bounded and lossy on purpose.
static LOG: Channel<CriticalSectionRawMutex, Line, 8> = Channel::new();

/// Machine-channel lines waiting for the radio. Separate from [`LOG`] because
/// the two transports drain at their own pace and a host on one shouldn't stall
/// the other - and because only protocol lines are worth a notification.
#[cfg(feature = "ble")]
static WIRE: Channel<CriticalSectionRawMutex, Line, 8> = Channel::new();

static DETENTS: AtomicI32 = AtomicI32::new(0);
static PRESSED: AtomicU8 = AtomicU8::new(0);
static VPP_ON: AtomicBool = AtomicBool::new(false);
static VERBOSE: AtomicBool = AtomicBool::new(false);
/// 0 = dark, 1 = dim heartbeat, 2 = full on (for finding the board).
static LED_MODE: AtomicU8 = AtomicU8::new(1);
/// Both radios self-start; the menu's `ble` row (or 'w') turns them off.
static RADIO_ON: AtomicBool = AtomicBool::new(true);
static SEQ: AtomicU8 = AtomicU8::new(0);
/// BAT+ / VDDH in millivolts, refreshed by the render loop.
static BATT_MV: AtomicU16 = AtomicU16::new(0);
/// 0 = off, 1 = starting, 2 = advertising, 3 = connected.
static LINK_STATE: AtomicU8 = AtomicU8::new(0);
static MENU_OPEN: AtomicBool = AtomicBool::new(false);
static MENU_SEL: AtomicU8 = AtomicU8::new(0);
/// 0 = the cube, 1 = the printer's gantry, 2 = the X-Carve, 3 = now playing,
/// 4 = subscription quotas, 5 = the orientation pattern.
///
/// The live input view and the all-pixels-on screen used to bracket these. Both
/// were bring-up instruments rather than things to look at: the pips told you a
/// switch was wired, which `p` also reports and every other screen now proves by
/// working, and lighting every pixel loaded VPP hard enough to find a weak boost
/// - on a board whose rail can't be gated anyway. The orientation pattern stays,
/// because a panel mounted the wrong way round is still worth one keystroke.
static VIEW: AtomicU8 = AtomicU8::new(0);
const VIEW_CUBE: u8 = 0;
const VIEW_GANTRY: u8 = 1;
const VIEW_XCARVE: u8 = 2;
const VIEW_MUSIC: u8 = 3;
const VIEW_QUOTA: u8 = 4;
const VIEW_PATTERN: u8 = 5;
const VIEWS: u8 = 6;
/// Gantry zoom, in detents off the resting size - see [`cube::zoom_scale`].
static ZOOM: AtomicI32 = AtomicI32::new(0);
/// Whether the gantry screen spells its positions out. The frame shows you
/// where the head is; the numbers say exactly, and get in the way of the view,
/// so they are a double tap away rather than always on.
static GANTRY_NUMBERS: AtomicBool = AtomicBool::new(false);
/// The step wheel, and what it is currently pointing at. Open only while a
/// button is held, so it can't be left on by accident.
static WHEEL_OPEN: AtomicBool = AtomicBool::new(false);
static WHEEL_SEL: AtomicU8 = AtomicU8::new(0);
/// The X-Carve menu's `zero` row, pressed once: when (ms since boot, never 0)
/// and for which axis. Zeroing throws away wherever zero was - a workpiece
/// you took five minutes to touch off - so it takes a second press on the same
/// axis inside [`ZERO_CONFIRM_MS`].
static ZERO_ARMED_MS: AtomicU32 = AtomicU32::new(0);
static ZERO_ARMED_AXIS: AtomicU8 = AtomicU8::new(0);
const ZERO_CONFIRM_MS: u32 = 3000;


/// The device's control model: three jog counters, one selected axis. The knob
/// drives the selected counter, BTN1/2/3 choose which. Everything on screen is
/// a view of this.
static AXIS_COUNTS: [AtomicI32; 3] =
    [AtomicI32::new(0), AtomicI32::new(0), AtomicI32::new(0)];
static AXIS: AtomicU8 = AtomicU8::new(0);

/// Which axis each button selects, in button order. The cube wanted Z, X, Y;
/// a gantry build that prefers X, Y, Z only has to change this line.
pub const BUTTON_AXIS: [usize; 3] = [2, 0, 1];
/// Why this boot happened, captured once and kept for the banner. The log
/// channel is lossy and boot is exactly when it overflows, so the one line that
/// explains a reboot loop is the one line that must not go through it.
static RESET_REASON: Mutex<CriticalSectionRawMutex, RefCell<&'static str>> =
    Mutex::new(RefCell::new("unknown"));

/// What the previous boot panicked with, waiting for someone to connect and
/// read it. Like [`RESET_REASON`], it stays out of the lossy log channel.
static PANIC_MESSAGE: Mutex<CriticalSectionRawMutex, RefCell<Option<Line>>> =
    Mutex::new(RefCell::new(None));
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
async fn main(_spawner: embassy_executor::Spawner) {
    let mut config = embassy_nrf::config::Config::default();
    // USBD needs the 64 MHz clock derived from HFXO; the nice!nano's MDBT50Q module
    // has the 32 MHz crystal. (Enabling `nfc-pins-as-gpio` also makes the first boot
    // after flashing write UICR and reset once - that is expected.)
    //
    // MPSL wants to own the CLOCK peripheral and hand the HF clock out through
    // `request_hfclk()`, so this is a conflict waiting to be resolved in the
    // radio build - but leaving it out did not fix MPSL's init hang and does
    // cost USB the crystal it wants, so the crystal stays until the radio
    // actually comes up.
    config.hfclk_source = HfclkSource::ExternalXtal;
    // MPSL puts RADIO/RTC0/TIMER0 at P0 and expects nothing else to compete;
    // the app's own interrupts sit below it in the ble build.
    #[cfg(feature = "ble")]
    {
        config.time_interrupt_priority = embassy_nrf::interrupt::Priority::P2;
    }
    let p = embassy_nrf::init(config);
    #[cfg(feature = "ble")]
    {
        use embassy_nrf::interrupt::{self, InterruptExt};
        interrupt::USBD.set_priority(interrupt::Priority::P2);
        interrupt::SPIM3.set_priority(interrupt::Priority::P2);
        interrupt::RNG.set_priority(interrupt::Priority::P2);
        interrupt::SAADC.set_priority(interrupt::Priority::P2);
    }

    // The 3V3 pad (OLED VDD, and the R2/R6 pull-ups) sits behind a load switch on
    // P0.13. Nothing on the puck outside the module is powered until this is high.
    let _vcc_en = Output::new(p.P0_13, Level::High, OutputDrive::Standard);
    let mut led = SimplePwm::new_1ch(p.PWM0, p.P0_15, &SimpleConfig::default());
    let mut boost = Boost::new(Flex::new(p.P1_06));

    // 4 MHz is well inside the SH1107's serial timing and pushes a whole 2 KB
    // frame in about 4 ms.
    let mut spi_config = spim::Config::default();
    spi_config.frequency = spim::Frequency::M4;
    let spi = Spim::new_txonly(p.SPI3, Irqs, p.P0_08, p.P0_17, spi_config);
    let mut screen = Display::new(
        spi,
        Output::new(p.P0_24, Level::High, OutputDrive::Standard), // CS, idle high
        Output::new(p.P0_06, Level::Low, OutputDrive::Standard),  // DC
        Output::new(p.P0_22, Level::High, OutputDrive::Standard), // RES, out of reset
    );

    // The nice!nano v2 senses the cell through VDDH rather than a divider pin,
    // so this reads VDDH/5 against the internal 0.6 V reference at gain 1/6.
    let mut battery = Saadc::new(
        p.SAADC,
        Irqs,
        saadc::Config::default(),
        [ChannelConfig::single_ended(VddhDiv5Input)],
    );

    let enc_a = Input::new(p.P0_09, Pull::Up);
    let enc_b = Input::new(p.P0_10, Pull::Up);
    // Order matches SWITCH_NAMES and the PRESSED bitmask.
    let switches = [
        Input::new(p.P0_31, Pull::Up),
        Input::new(p.P0_02, Pull::Up),
        Input::new(p.P1_15, Pull::Up),
        Input::new(p.P1_11, Pull::Up),
    ];

    // ---- USB CDC-ACM ----
    let driver = Driver::new(p.USBD, Irqs, HardwareVbusDetect::new(Irqs));
    let mut usb_config = Config::new(0x1209, 0x0001); // pid.codes prototype VID/PID
    usb_config.manufacturer = Some("softek");
    usb_config.product = Some("pico2joy bring-up");
    usb_config.serial_number = Some("pico2joy-1");
    usb_config.max_power = 100;
    usb_config.max_packet_size_0 = 64;

    let mut config_descriptor = [0u8; 256];
    let mut bos_descriptor = [0u8; 256];
    let mut msos_descriptor = [0u8; 0];
    let mut control_buf = [0u8; 64];
    let mut cdc_state = State::new();

    let mut builder = Builder::new(
        driver,
        usb_config,
        &mut config_descriptor,
        &mut bos_descriptor,
        &mut msos_descriptor,
        &mut control_buf,
    );
    let class = CdcAcmClass::new(&mut builder, &mut cdc_state, 64);
    let mut usb = builder.build();
    let (mut tx, mut rx) = class.split();

    // ---- host commands ----
    let reason = reset_reason();
    RESET_REASON.lock(|cell| *cell.borrow_mut() = reason);
    logln!("boot: reset reason {reason}");
    if let Some((count, message)) = take_panic_message() {
        logln!("boot: last boot panicked ({count} in a row): {message}");
        PANIC_MESSAGE.lock(|cell| *cell.borrow_mut() = Some(message));
    }

    let commands = async {
        let mut buf = [0u8; 64];
        // The machine channel shares the port with the console: '#' opens a line
        // for [`gantry`] to parse, everything else stays a single keystroke.
        let mut proto: String<96> = String::new();
        let mut in_proto;
        // Keys held back during the echo window, see [`ECHO_PROBE`].
        let mut held: Vec<u8, 32> = Vec::new();
        // How far into the greeting the echo has got, and how many bytes have
        // agreed with it.
        let mut cursor = 0usize;
        let mut score = 0usize;
        // The greeting they belong to: a new one starts them over.
        let mut armed = 0u32;
        fn release(held: &mut Vec<u8, 32>) {
            for &byte in held.iter() {
                console_key(byte);
            }
            held.clear();
        }
        // Time left in the echo window, if it is open.
        fn echo_window() -> Option<Duration> {
            let greeted = GREETED_MS.load(Ordering::Relaxed);
            if greeted == 0 {
                return None;
            }
            let since = (Instant::now().as_millis() as u32).wrapping_sub(greeted);
            ECHO_WINDOW.as_millis().checked_sub(since as u64).map(Duration::from_millis)
        }
        loop {
            rx.wait_connection().await;
            in_proto = false;
            held.clear();
            loop {
                // Keys held for the window are released when it closes, even
                // if nothing else arrives.
                let read = match echo_window() {
                    Some(left) if !held.is_empty() => {
                        match with_timeout(left, rx.read_packet(&mut buf)).await {
                            Ok(read) => read,
                            Err(_) => {
                                release(&mut held);
                                continue;
                            }
                        }
                    }
                    _ => {
                        release(&mut held);
                        rx.read_packet(&mut buf).await
                    }
                };
                let Ok(n) = read else { break };
                for &byte in &buf[..n] {
                    if in_proto {
                        // '#' never appears inside a line, so seeing one means
                        // the last line was cut short: start the new one.
                        if byte == b'#' {
                            proto.clear();
                            continue;
                        }
                        if byte == b'\n' || byte == b'\r' {
                            in_proto = false;
                            machine_line(&proto);
                            proto.clear();
                        } else if proto.push(byte as char).is_err() {
                            // Longer than any line we define: drop it rather
                            // than parse half of one.
                            in_proto = false;
                            proto.clear();
                        }
                        continue;
                    }
                    // Opens the machine channel. Deliberately the *only* way
                    // to reach anything destructive: a single key that
                    // rebooted the puck would also fire on the tail of a
                    // protocol line whose '#' went missing, and "#s ..." ends
                    // up spelling console commands.
                    if byte == b'#' {
                        release(&mut held);
                        in_proto = true;
                        proto.clear();
                        continue;
                    }
                    if ECHO_MUTED.load(Ordering::Relaxed) {
                        continue;
                    }
                    if echo_window().is_none() {
                        release(&mut held);
                        console_key(byte);
                        continue;
                    }
                    // Inside the window: hold the key, and see whether it is
                    // the next thing an echo of the greeting would contain.
                    let greeted = GREETED_MS.load(Ordering::Relaxed);
                    if greeted != armed {
                        armed = greeted;
                        cursor = 0;
                        score = 0;
                    }
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

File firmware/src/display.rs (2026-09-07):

//! ER-OLED1.12-2 (SH1107, 128x128) on the J3 ribbon, 4-wire SPI.
//!
//! Geometry is SSD1306-shaped: 16 pages of 128 columns, one byte per page column
//! holding 8 vertically stacked pixels with D0 at the top. Bytes shift out MSB
//! first on the rising edge of SCLK (SPI mode 0) and DC (the SH1107's A0) is
//! sampled on every eighth clock, so it can be toggled with CS held low.
//!
//! The panel's own DC-DC stays off (`0xAD 0x8A`): VPP is external, from U2's 12 V
//! boost. Bring VPP up before enabling the display, and drop the display before
//! VPP on the way down.

use embassy_nrf::gpio::Output;
use embassy_nrf::spim::Spim;
use embassy_time::Timer;
use embedded_graphics::pixelcolor::BinaryColor;
use embedded_graphics::prelude::*;

pub const WIDTH: u32 = 128;
pub const HEIGHT: u32 = 128;
const COLS: usize = WIDTH as usize;
const PAGES: usize = HEIGHT as usize / 8;

/// Vendor init sequence (ER-OLED1.12-2 4-wire SPI sample), display left off.
const INIT: &[u8] = &[
    0xAE, // display off
    0xD5, 0x50, // clock divide / frame frequency ~104 Hz
    0x20, // page addressing mode
    0x81, 0x4F, // contrast
    0xAD, 0x8A, // DC-DC off: VPP supplied externally
    0xC0, // COM scan direction, normal
    0xA0, // segment remap, normal
    0xDC, 0x00, // display start line
    0xD3, 0x00, // display offset
    0xD9, 0x22, // pre-charge / discharge period
    0xDB, 0x35, // VCOMH deselect level
    0xA8, 0x7F, // multiplex ratio = 128
    0xA4, // follow RAM contents
    0xA6, // normal, not inverted
];

pub struct Display<'d> {
    spi: Spim<'d>,
    cs: Output<'d>,
    dc: Output<'d>,
    res: Output<'d>,
    fb: [u8; COLS * PAGES],
    contrast: u8,
    flipped: bool,
}

impl<'d> Display<'d> {
    pub fn new(spi: Spim<'d>, cs: Output<'d>, dc: Output<'d>, res: Output<'d>) -> Self {
        Self {
            spi,
            cs,
            dc,
            res,
            fb: [0; COLS * PAGES],
            contrast: 0x4F,
            flipped: false,
        }
    }

    /// Hardware reset, then the vendor init. Leaves the display off and the RAM
    /// cleared, ready for VPP to come up.
    pub async fn init(&mut self) {
        self.res.set_low();
        Timer::after_millis(10).await;
        self.res.set_high();
        Timer::after_millis(50).await;

        self.cmds(INIT).await;
        self.fb.fill(0);
        self.flush().await;
    }

    pub async fn on(&mut self) {
        self.cmds(&[0xAF]).await;
    }

    pub async fn off(&mut self) {
        self.cmds(&[0xAE]).await;
    }

    pub fn contrast(&self) -> u8 {
        self.contrast
    }

    pub async fn set_contrast(&mut self, contrast: u8) {
        self.contrast = contrast;
        self.cmds(&[0x81, contrast]).await;
    }

    pub fn flipped(&self) -> bool {
        self.flipped
    }

    /// Rotate the panel 180 degrees, for when the puck is assembled the other way
    /// up. Only affects what the controller does with RAM, not the framebuffer.
    pub async fn set_flipped(&mut self, flipped: bool) {
        self.flipped = flipped;
        if flipped {
            self.cmds(&[0xC8, 0xA1]).await;
        } else {
            self.cmds(&[0xC0, 0xA0]).await;
        }
    }

    pub fn clear(&mut self) {
        self.fb.fill(0);
    }

    /// Replace the whole framebuffer with bytes already in the panel's layout.
    ///
    /// This is the fast path for a full-screen bitmap the host has packed to
    /// match: 16 pages of 128 columns, D0 at the top, and the same logical->panel
    /// rotation [`Self::set_pixel`] applies, so text drawn afterwards through the
    /// normal path lands on top in the right place. A cover, in other words.
    pub fn blit_raw(&mut self, buf: &[u8; COLS * PAGES]) {
        self.fb.copy_from_slice(buf);
    }

    /// Writes one logical pixel, rotating it into the panel's frame.
    ///
    /// This panel's RAM sits 90 degrees to the glass: an SH1107 page runs along
    /// what you see as the horizontal axis. The controller can't help - segment
    /// remap and COM direction only get you 180 - so the rotation happens here,
    /// on the way into the framebuffer, and everything above this line gets to
    /// think in ordinary screen coordinates.
    ///
    /// Logical (x, y) lands at panel column `y`, row `127 - x`. The `127 - x` is
    /// the part that matters: a bare transpose (column `y`, row `x`) rotates *and*
    /// mirrors, which reads as "nearly right, but backwards".
    pub fn set_pixel(&mut self, x: usize, y: usize, on: bool) {
        if x >= COLS || y >= HEIGHT as usize {
            return;
        }
        let (column, row) = (y, HEIGHT as usize - 1 - x);
        let byte = &mut self.fb[(row / 8) * COLS + column];
        let mask = 1 << (row % 8);
        if on {
            *byte |= mask;
        } else {
            *byte &= !mask;
        }
    }

    /// Push the whole framebuffer. ~4 ms at 4 MHz, with an await between pages so
    /// input polling still gets its 1 kHz slot.
    pub async fn flush(&mut self) {
        for page in 0..PAGES {
            self.cs.set_low();
            self.dc.set_low();
            // page address, then column 0 as low nibble + high nibble
            let _ = self.spi.write(&[0xB0 | page as u8, 0x00, 0x10]).await;
            self.dc.set_high();
            let _ = self
                .spi
                .write(&self.fb[page * COLS..(page + 1) * COLS])
                .await;
            self.cs.set_high();
        }
    }

    async fn cmds(&mut self, bytes: &[u8]) {
        self.cs.set_low();
        self.dc.set_low();
        let _ = self.spi.write(bytes).await;
        self.cs.set_high();
    }
}

impl OriginDimensions for Display<'_> {
    fn size(&self) -> Size {
        Size::new(WIDTH, HEIGHT)
    }
}

impl DrawTarget for Display<'_> {
    type Color = BinaryColor;
    type Error = core::convert::Infallible;

    fn draw_iter<I>(&mut self, pixels: I) -> Result<(), Self::Error>
    where
        I: IntoIterator<Item = Pixel<Self::Color>>,
    {
        for Pixel(point, colour) in pixels {
            if point.x >= 0 && point.y >= 0 {
                self.set_pixel(point.x as usize, point.y as usize, colour.is_on());
            }
        }
        Ok(())
    }
}

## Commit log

2026-06-23 Initial hardware: nice!nano BLE knob — schematic + routed PCB + mockup
    Wireless control puck (nice!nano v2 / nRF52840 + LiPo): EC11 encoder, 3
    tactile buttons, 0.87" SSD1316 I2C OLED on female sockets. Ø80mm round
    2-layer board, nano back-mounted, GND pours both sides, fully routed,
    DRC-clean (0 errors).
    Script-generated (scripts/gen_sch.py, gen_pcb.py) + freerouting + manual
    encoder routing. Includes FreeCAD mechanical mockup (cad/mockup.py) and
    component STEP models. See README for the reviewer notes.
    [encoder.step, nicenano.step, oled.step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]
2026-06-23 Attach nano + encoder 3D models (KiCad ships neither)
    Link cad/step/nicenano.step to U1 and cad/step/encoder.step to RE1 via
    project-relative paths so the 3D preview / board STEP export are complete.
    Standard parts (buttons, OLED header, JST, resistors) already had models.
    [pico2-knob.kicad_pcb]
2026-06-23 Center button arc, offset OLED header, add nano standoff + OLED 3D model
    - Buttons: SW_PUSH_6mm origin is its top-left pad (+3.25mm X from body
    center); shift origins so the visible arc is symmetric about the centerline.
    - OLED header J1 moved ~18mm left so the plugged-in module's glass centers
    over the knob (per the module MCAD drawing).
    - nano 3D model dropped 8.5mm onto its sockets (clears the encoder peg).
    - Attach oled.step to J1 as a 3D model (glass-centering check in KiCad 3D).
    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
    [pico2-knob.kicad_pcb]
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2026-06-23 Finalize PCB: trimmed outline, lowered encoder, 4x M3 mounting holes
    - Outline shrunk to a Ø74 vertical lens (flat left/right trims, empty space).
    - Encoder lowered 8mm; nano nudged down to clear the smaller top rim.
    - 4x M3 NPTH mounting holes (board-only): 3 corners + an inset top-left.
    - Includes hand-routing/placement (R1/R2/J2 moves, VBAT @0.4mm, the 3 manual
    ratsnest routes) done in the GUI. Ratsnest 0, DRC 0 violations.
    NOTE: board is hand-finalized past gen_pcb.py (scaffold only now) -- the .kicad_pcb
    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
    [pico2-knob.kicad_pcb]
2026-06-24 Add 3D-printed housing: lower tray + top cover (FreeCAD)
    Lower tray: round Ø81 (Ø76 cavity), 4 M3 heat-set posts at the mounting
    holes, snap-fit groove, USB-C charging cutout, battery corral ribs.
    Top cover: snap-on cap with encoder-shaft / OLED-window / 3-button cutouts.
    Parametric (cad/housing.py, cad/cover.py) + saved model (cad/pico2_housing.FCStd).
    [pico2_housing.FCStd]
2026-07-27 Rebuild schematic + fresh project files after project-state corruption
    - Reorganize repo: hardware/ -> board_pico2knob/, cad/ -> mechanical/,
    add automation/ (Konnect MCP client + autoroute scripts), docs, konnect.toml
    - Rebuild schematic from scratch after corrupted .kicad_pro/.kicad_prl broke
    junction connectivity (identical .kicad_sch worked standalone but failed
    under the project name; old project files archived for bug reporting)
    - Fresh minimal .kicad_pro; symbol UUIDs preserved so board relinks via F8
    - Restore board placement (35 footprints, outline, mounting holes)
    - ER-OLED1.12-2 screen: SH1107 OLED on 20-pin FPC (J3/DS1), MC34063 12V
    boost for VPP with 12V_EN gate switch,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
    [backuppico2-knob.kicad_pcb, encoder.step, nicenano.step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]
2026-07-27 finished pcb? erc/drc passing, need export
    [inductor.step, pico2-knob.FCStd, pico2-knob.kicad_pcb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]
2026-07-27 remove mounting holes
    [backuppico2-knob.kicad_pcb, pico2-knob.kicad_pcb]
2026-07-29 pre-U2 flip
    [pico2-knob.kicad_pcb, pico2-knob.kicad_sch]
2026-08-03 not sure bump
    [pico2-knob.kicad_pcb]
2026-08-03 passing erc/drc
    [pico2-knob.kicad_pcb, pico2-knob.kicad_sch]
2026-08-03 add silkscreens, copper lightning bolts export gerbers
    [pico2-knob-B_Courtyard.gbr, pico2-knob-B_Cu.gbl, pico2-knob-B_Fab.gbr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]
2026-08-04 mounting holes, gerber export
    [pico2-knob-B_Courtyard.gbr, pico2-knob-B_Cu.gbl, pico2-knob-B_Fab.gbr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]
2026-09-03 FEAT: fw: bring-up firmware for the nice!nano puck
    Rust + Embassy on the nice!nano v2, flashed as UF2 over the stock bootloader
    (app at 0x26000, above the untouched S140 slot). Verified on the assembled
    board: encoder, all three buttons, the SH1107 ribbon OLED and the 12 V panel
    rail.
    - USB CDC console streams every encoder detent and button edge, with a
    single-key command set (pin dump, view cycle, contrast, display re-init,
    180 flip, 12 V rail, LED mode, reboot-to-bootloader).
    - SH1107 driver follows EastRising's own 4-wire SPI sample: external VPP via
    0xAD 0x8A, and set_pixel rotates logical (x, y) to panel column y, row
    127 - x, because this panel's RAM sits 90 degrees to the gl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
    [display.rs, main.rs]
2026-09-03 FEAT: fw: opt-in BLE link, and stop a bad build going dark
    Adds a connectable GATT link behind `--features ble` (trouble-host on the
    Nordic SoftDevice Controller, so no SoftDevice binary and the app stays at
    0x26000). One service, one notify characteristic carrying the same payload
    the raw advertiser sends, and no Security Manager at all: a central connects
    and subscribes with no pairing prompt, no key material either side, and
    nothing written to flash.
    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
2026-09-03 FEAT: fw: battery meter and an on-device menu
    The puck can now be driven without a cable: press the knob to open a menu,
    turn to move, press to act, BTN3 to back out. Rows are ble, 12V rail, led,
    screen, battery and exit, each showing its current value, and every row routes
    through the same request flags the console commands use so each action has one
    implementation. `m` on the console opens it too, which is the only way to test
    it without hands on the hardware.
    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
2026-09-03 FEAT: fw: axis jog model, and a gantry view that renders it
    The puck is a 3-axis jog controller, so make that the primitive rather than a
    feature of one screen: three jog counters plus a selected axis, driven by the
    knob and BTN1/2/3, with every screen a view of it. BUTTON_AXIS is one line -
    Z, X, Y in button order as asked, trivially X, Y, Z instead. The console drives
    the same model with 1/2/3 and , . so it can be exercised without hands on the
    hardware.
    The gantry view renders the counters as a rotating wireframe cube with the
    three counts along the bottom, selected axis inverted. Hidden edges are hidden
    properly: on a convex solid, hidden-line removal is backface culling, so an
    edge is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
    [cube.rs, main.rs]
2026-09-05 first "complete" mvp - lower half battery connector pocket extended post-print
    [pcb_nubbin_mount.FCStd, pico2-knob.FCStd, pico2_housing.FCStd]
2026-09-05 FEAT: fw: printer-driven gantry, cube momentum, reboot diagnostics
    Three things the puck learned, all views of the same jog model.
    The gantry screen is the real machine: positions, travel and homed state
    come from the host (src/gantry.rs), a detent produces a jog *request* in
    micrometres, and nothing on screen moves until the printer says the head
    did. A jog that would be refused - unhomed, mid-print, past a limit -
    never leaves the puck. No `#s` for 1.2 s and the screen says `offline`
    rather than freezing a stale pose.
    The cube keeps its own momentum now: a detent is torque, not position,
    so a flick sets it coasting and a counter-flick stops it. Buttons there
    are momentary - hold one to s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
    [main.rs]
2026-09-05 WIP: fw: ble machine channel, and an mpsl init that never returns
    The puck service gains the same line protocol the USB console carries:
    a write characteristic the host feeds lines into, a notify one for the
    lines coming back, in 20-byte pieces because that is what fits an
    unnegotiated ATT MTU. Both transports land in `machine_line`, so the
    host tool speaks one protocol either way.
    None of it is reachable yet. `MultiprotocolServiceLayer::new` does not
    return on this board: the console goes with it, the panic box stays
    empty, and the watchdog is what ends it - so it is a hang inside
    `mpsl_init`, not a fault. Tried and ruled out, each on hardware:
    skip_wait_lfclk_started, letting MPSL own the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
2026-09-05 FEAT: tools: one host program for the puck, over usb or ble
    `pico2joy.py` replaces gantry_bridge.py and does the lot: scan, monitor,
    gantry relay, flash over USB, OTA over BLE, and reboot into a bootloader
    mode. The transport is a detail above the line protocol, so every
    subcommand takes --link usb|ble|auto.
    Nobody here is a server. This is a client of everything - it opens the
    puck's port or connects as a BLE central, and makes HTTP requests to
    Moonraker, which is the only real server involved. So it runs wherever
    the puck is attached, with no listening socket and no discovery, and
    the only hard rule is that one copy owns the puck at a time.
    Standard library only for the USB paths: the pr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
2026-09-05 DOCS: fw: the gantry relay, and flashing without the button
    The gantry view is a real printer now, so the README says how: the wire
    format both ways, where the relay belongs (the printer host, where
    Moonraker is localhost and trusted) and how to run it from a workstation
    that isn't in trusted_clients.
    Also: the cube's momentum and momentary buttons, the menu's new rows and
    the knob-in-knob-out controls, and pico2joy.py in place of the bridge.
    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
2026-09-07 FEAT: fw: knob acceleration, a step wheel, and an isometric gantry view
    Turn the knob slowly and a detent is exactly the step you chose; turn it
    quickly and each detent is worth more. `accel` is a power law on the
    smoothed detent rate - floor, exponent, ceiling - with a menu row to pick
    a profile, and the gantry screen shows the gain while it applies.
    Hold an axis button and the step sizes fan out around the knob as a
    wheel: turn to pick one, let go to keep it. Double-tap toggles the
    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
2026-09-07 FIX: fw: stop a cooked host tty echoing the console into a reboot
    Linux hands every freshly enumerated ttyACM over in cooked mode with
    echo on, and a tty with echo on sends everything the puck prints straight
    back into its command parser. A log packet was always left queued in the
    IN endpoint while nothing was reading, so the host delivered and echoed
    it during open(), before the relay's tcsetattr could go raw - and "view:
    cube" or "boot: reset reason" contain 'b', the reboot key. With a battery
    fitted the bootloader then stays put across replugs: the "jumps to
    FLASHING on plug and gets stuck" report.
    Three defences. Nothing is written unless DTR is up, so nothing queues
    for the next opener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
    [main.rs]
2026-09-07 DATA: mech: housing v2 shells, nubbin mount, print file and paste stencils
    The FreeCAD model as it stands after the battery-pocket rework, with the
    v2 upper and lower shells and the display back exported as STEP, the 3MF
    for printing, and the OpenSCAD paste stencils (top, bottom, bottom
    without J3, and an FDM-printable bottom) cut from the board's paste and
    edge-cuts DXFs.
    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
    [bottomStencil-fdm-noJ3.scad, bottomStencil-fdm-noJ3.stl, bottomStencil-noJ3.scad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]
2026-09-07 FEAT: fw: the BLE link comes up - share CLOCK_POWER, hold the crystal
    MPSL init no longer hangs. CLOCK_POWER is one interrupt for two
    peripherals: USB's VBUS detection on the POWER half, MPSL's clock
    management on the CLOCK half. The ble build bound it to MPSL alone, so
    the USB events the bootloader leaves armed were never cleared and
    stormed the moment MPSL enabled the line - which read as "mpsl_init
    never returns". Now `main` binds the line to USB's handler and to a
    gated forwarder (`ble::ClockGate`) that only calls MPSL once init has
    run, so POWER events are cleared first and CLOCK ones reach MPSL.
    With the stack up: keep USB alive by holding MPSL's HFCLK request, since
    the crystal USB n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
    [main.rs]
2026-09-07 FIX: tools: correct DFU UUIDs and receipt flow, name the ble UF2
    The over-the-air path had three bugs that stopped it dead. The DFU
    service UUIDs were truncated (missing the last bytes), so bleak threw
    "badly formed hexadecimal UUID string" before it could talk to the
    bootloader; they now match the Adafruit bootloader's 1530/1531/1532.
    The DFU target advertises as "AdaDFU", not "pico2joyDFU", so that is the
    default the scan filter looks for. And packet-receipt notifications were
    counted as if each were the reply to a control opcode, so `expect`
    consumed a receipt and then read garbage; it now skips 0x11 receipts and
    the transfer loop waits until a receipt's byte count covers what was
    sent, w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
2026-09-07 FEAT: tools: a spotify/MPRIS bridge that relays cover art to the puck
    `pico2joy.py spotify` maps the puck's buttons and knob to the active MPRIS
    player via playerctl (following playerctld) and streams the album art back
    as a 128x128 one-bit cover. It deliberately avoids Spotify's Web API - no
    OAuth, no Premium requirement, nothing to break on their next API change -
    and works against the Spotify web player in a browser exactly as against a
    desktop app. Volume is the host's own output via wpctl or pactl, which is
    what "volume on the relay host" means.
    Pillow (declared inline, fetched by uv) decodes and Floyd-Steinberg dithers
    the cover; it packs into the panel framebuffer layout so the firmw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
2026-09-07 FIX: tools: keep the now-playing bridge's #ns heartbeat flowing
    The puck falls back to "no bridge" when `#ns` goes quiet for two seconds,
    but poll() only sent it on a track or volume change, so idle playback timed
    out and the music screen flapped. Send `#ns` every poll now, carrying play
    state and volume, the same way the gantry streams `#s` unconditionally.
    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
2026-09-07 FEAT: fw: a quota screen, an app switcher, and two screens fewer
    A fifth app: how much of each Claude and Codex plan's rate-limit windows is
    spent, and how long until the short one starts again. `quota.rs` has the same
    shape as `gantry.rs` and `media.rs` - the puck is a view of the host, never a
    second copy of it. The bridge reads the vendors; nothing here decides what a
    percentage means.
    One number is computed locally, and only one: the countdown. The bridge sends
    the seconds left at the moment it asked and the puck turns that into a deadline
    on its own clock, so the minutes tick between polls instead of freezing. Every
    poll re-syncs it - the same bargain the gantry makes with toolhead pos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
    [main.rs]
2026-09-07 FEAT: fw: the connectable ble link becomes the default build
    The puck's whole point is being wireless, and the host relay now follows it
    over BLE for as long as it is powered - so the build that can accept a
    connection is the one `./build.sh`, `cargo run` and `pico2joy.py flash` should
    produce. `out/pico2joy-bringup.uf2` is that build.
    The broadcast-only firmware is still here as `./build.sh --no-ble` ->
    `pico2joy-bringup-noble.uf2`: a quarter of the flash, no radio stack to go
    wrong, and useful when bisecting. `--ble` is accepted and says it does nothing,
    because the muscle memory will outlive the flag.
    The two critical-section implementations still cannot both be linked, so the
    fallback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
2026-09-07 FEAT: tools: quota bridge, and a ble link that reconnects itself
    Two things in one file, because they are one program.
    The quota bridge is a third app on the relay's one link, chosen by `#view` like
    the other two. It reads the credentials each vendor's CLI already keeps on disk
    and asks the same usage endpoints those CLIs ask - nothing is counted here and
    nothing is reconstructed from transcripts, because a local token tally would be
    a second, wronger copy of a number the vendor is authoritative for.
    Read-only, deliberately: those access tokens are the CLIs' to refresh, and using
    the refresh token here could rotate it out from under a running session and log
    someone out of their editor to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
2026-09-11 DOCS: fw: driving the x-carve
    A section on the X-Carve screen and its bridge: where it runs, how it shares
    the machine with CNCJS, and what GRBL changes next to Klipper - work
    coordinates, "homed" meaning "not in Alarm" and why `$X` without homing is the
    thing to avoid on a machine with soft limits off, and `$J=` jogs. Plus the new
    screen in the `d` cycle and the command list.
    Claude-Session: https://claude.ai/code/session_01WSG6Xg3ZxaGTimuPZj5Qr7
2026-09-11 FEAT: fw: zero the x-carve from the puck, and a jog floor it can move
    The X-Carve's menu gains a first row, `zero X`, for whichever axis BTN1/2/3
    last picked: it asks the bridge to make the head's position that axis's work
    zero, so touching off a workpiece no longer needs the CNCJS page. A zero throws
    away wherever zero was, so it takes a second press on the same axis within
    three seconds - the row says `again?` - and turning the knob in between
    cancels it. Once it zeroes the menu closes, and 0.00 is the next thing seen.
    That row makes the X-Carve's menu ten long, one more than fits under the title
    bar, so the menu is now a list per screen and scrolls: the window follows the
    selection, with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
    [main.rs]
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2026-09-25 FIX: tools: xcarve knob no longer coasts on after you stop turning
    The relay sent every gathered detent as a $J= move no matter how far
    behind the gantry was, so a fast spin banked travel in CNCJS and the
    GRBL planner and the head ran on long after the hand stopped (156 mm
    in simulation for a hard 10 mm-step spin).
    Now it paces sends against its own estimate of when GRBL will finish
    (--jog-lead, 0.15 s), caps what a burst can gather to what the machine
    could cover, and once ticks have had to be dropped, a stopped knob
    sends jogCancel (0x85) so the head decelerates where it is (7.5 mm).
    Slow turns and a lone detent of any size still land exactly.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
2026-10-15 DATA: hw: Q1 bodge preview, the leg swap drawn on the real copper
    Q1 (DMG3415U) is in backwards on this revision: the schematic puts its drain
    on +BATT and its source on U2's Vin, and the SOT-23 pads carry that onto the
    board, so the body diode feeds the boost whenever a cell is in and 12V_EN
    gates nothing. ERC can't see it, since both pins are typed passive.
    The preview crops the top copper around Q1 from the board file and overlays
    the bodge: lift the source and drain legs, wire source to the +BATT pad and
    drain to the U2 Vin pad, leave the gate leg and R8 alone. Beside it, the
    as-built and after-bodge schematic with the body diode drawn in. Rev 2 swaps
    S and D in the symbol; the footprin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
2026-10-30 FEAT: hw: rev2 schematic and layout
    Q1 fix drawn in, mounting holes reworked. Saved minutes before the rev2 gerbers were exported on 10-15. .kicad_pro churn from a KiCad upgrade dropped.
    Claude-Session: https://claude.ai/code/session_01WNyZb2r3g3gmPdh6UyGJC4
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

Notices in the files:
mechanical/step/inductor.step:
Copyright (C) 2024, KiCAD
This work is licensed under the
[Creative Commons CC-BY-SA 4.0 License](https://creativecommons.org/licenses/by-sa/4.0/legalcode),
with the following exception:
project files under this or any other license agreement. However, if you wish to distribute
